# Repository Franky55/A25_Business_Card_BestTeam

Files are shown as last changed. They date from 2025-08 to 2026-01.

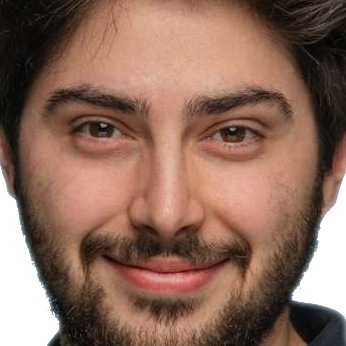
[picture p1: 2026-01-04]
code/web/photos/frank.png

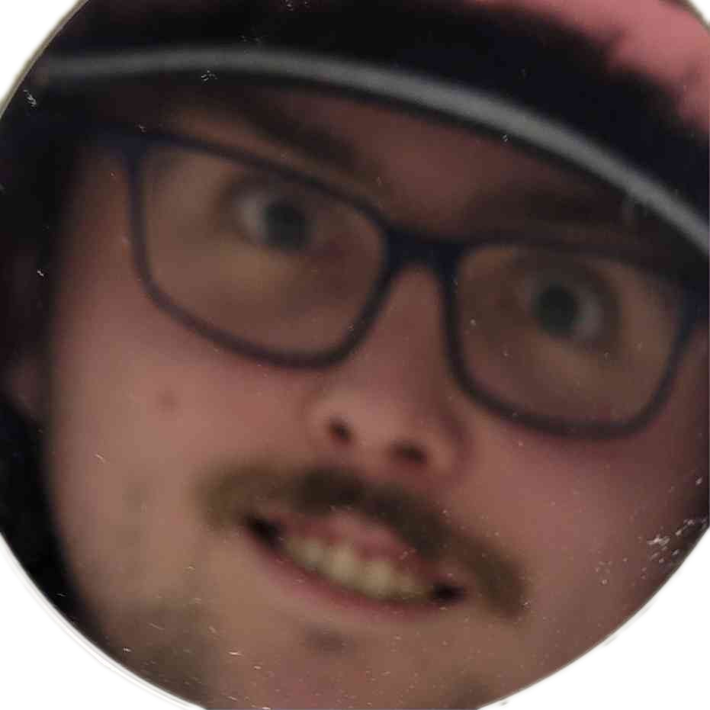
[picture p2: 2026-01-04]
code/web/photos/julien.png

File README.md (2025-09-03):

# C3I A25\_Business\_Card

Concours de Conception de Circuits Imprimés – Université de Sherbrooke, Automne 2025

## Thème : Carte professionnelle (Business Card)

Bienvenue à la compétition de conception de PCB de l’Université de Sherbrooke, édition automne 2025 !
Cette année, le défi est de transformer la carte professionnelle traditionnelle en un **objet électronique unique, créatif et fonctionnel**.
Votre mission : concevoir un PCB au format carte de visite qui intègre des fonctionnalités innovantes, esthétiques et utiles dans un contexte professionnel réel.

---

## Déroulement

Capture d’écran du 2025-09-03 15-49-03

* **25 août** : Lancement de la compétition et ouverture des inscriptions
* **3 octobre** : Date limite d’inscription
* **10 octobre** : Date limite de sélection d’idée (formulaire fourni sur GitHub et Discord)
* **25 août au 31 décembre 23h59** : Période de conception et développement
* **Dates de commande des PCB et pièces** :

  * 19 septembre\* (LCSC)
  * 3 octobre\* (LCSC)
  * 17 octobre\* (LCSC)
  * 31 octobre\* (LCSC)
  * 14 novembre
  * 28 novembre
  * 12 décembre\*\* (commande finale, réception non garantie avant la fin)
* **Décembre** : Finalisation des projets
* **31 décembre 23h59** : Remise finale (schémas, Gerber, BOM, photos, doc)
* **5 janvier 2026** : Journée de l’événement et présentations publiques

---

### Répertoire "Template"  
Le répertoire "Template" contient tous les documents à remplir pour participer à la compétition. Vous y trouverez :  
- Formulaire d'idée (à remplir)
- Formulaire d'inscription (à remplir)
- Condition et termes de l'inscription
- TEMPLATE de PowerPoint
- TEMPLATE pour la documentation

---

### Répertoires code, elec et mech  
Chacun de ces répertoires contient de la documentation de départ pour vous guider. Consultez la section "doc". Ces répertoires sont également là pour vous aider à vous organiser lors du développement de votre règle.

---

### Comment forker le dépôt

1. Accédez au dépôt GitHub officiel à l'adresse suivante : `https://github.com/CCI-udes/H25_Pomodoro`.
2. Cliquez sur le bouton "Fork" en haut à droite de la page du dépôt.
3. Sélectionnez votre propre compte GitHub comme destination du fork.
4. Clonez le dépôt forké sur votre machine locale en utilisant la commande suivante :
   ```bash
   git clone https://github.com/<votre-utilisateur>/E25_Wearable.git
   ```

---

## Règlement

* Équipes de **1 à 3 personnes**
* Frais de participation : **10 \$ / membre** OU **courriel de commandite** (gabarits fournis)
* Dimensions maximales PCB : **88,9 mm x 50,8 mm**
* BOM maximum : **50 \$**
* Coût de développement total : **125 \$**
* Utilisation de **DevBoard permise** (pénalité de points si dans la version finale)
* Tous les types de composants acceptés (Bluetooth, NFC, OLED, etc.)
* Batterie rechargeable permise si formation suivie et protocole respecté
* Objectif : **s’amuser et apprendre** !

---

## Remise

Chaque équipe doit fournir via son fork GitHub :

* Schéma électrique (PDF)
* Fichiers Gerber du PCB + projet EDA OU PDF coloré des couches
* Photo(s) du PCB assemblé (avec et sans boîtier)
* BOM conforme aux normes C3I
* Documentation complète du projet

---

## Évaluation

Les projets seront notés sur un total de **250 points**, selon :

* **Idée \[15 pts]** (juges + vote des participants)
* **Fonctionnalité \[35 pts]** (implémentation et compréhension)
* **Complexité \[45 pts]** (hardware + software)
* **Gestion des ressources \[25 pts]** (BOM + commandes)
* **Démonstration \[55 pts]** (oral, écrit, esthétique)
* **Conception électronique \[75 pts]** (choix composants, schéma, PCB, assemblage, soudures)

---

## Prix

* 🏆 **Prix de conception** – Total 250 pts
* ⚡ **Prix du gningnégnieur** – Total 170 pts (créativité et apprentissage valorisés)
* 💼 **Prix du vendeur** – Total 125 pts (gestion, organisation, finition)

---

## Ressources utiles

* **Microcontrôleurs recommandés** : ESP32-C3, ESP32-S3, RP2040, RP2350, ch32v003
* **Logiciels de conception** : KiCad, Altium, EasyEDA (+ tutoriels fournis dans le doc)
* **Idées de business cards électroniques** : [Hackaday](https://hackaday.com/tag/pcb-business-card/), [Reddit](https://www.reddit.com/r/PCB/comments/14jk8cz/pcb_business_card_ideas/), [Exemples NFC](https://www.instructables.com/PCB-Business-Card-With-NFC/)
* **Discord** : [Lien d’invitation](https://discord.gg/xeSqf3N3Hw)

---

## Contacts

* Jacob Turcotte – Président – `Jacob.Turcotte@usherbrooke.ca`
* Miriam Caisse – Vice-présidente – `Miriam.Caisse@usherbrooke.ca`
* Jordan Gagnon – Trésorier – `Jordan.Gagnon@usherbrooke.ca`
* Céleste-Lyi Martel – Marketing – `Celeste-lyi.martel@usherbrooke.ca`

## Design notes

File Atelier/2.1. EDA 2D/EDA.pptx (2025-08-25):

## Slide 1

Les logiciels d'EDA,
Electronic Design Automation
par où commencer ?

Présentation par : Miriam Caisse
Groupe technique CCI

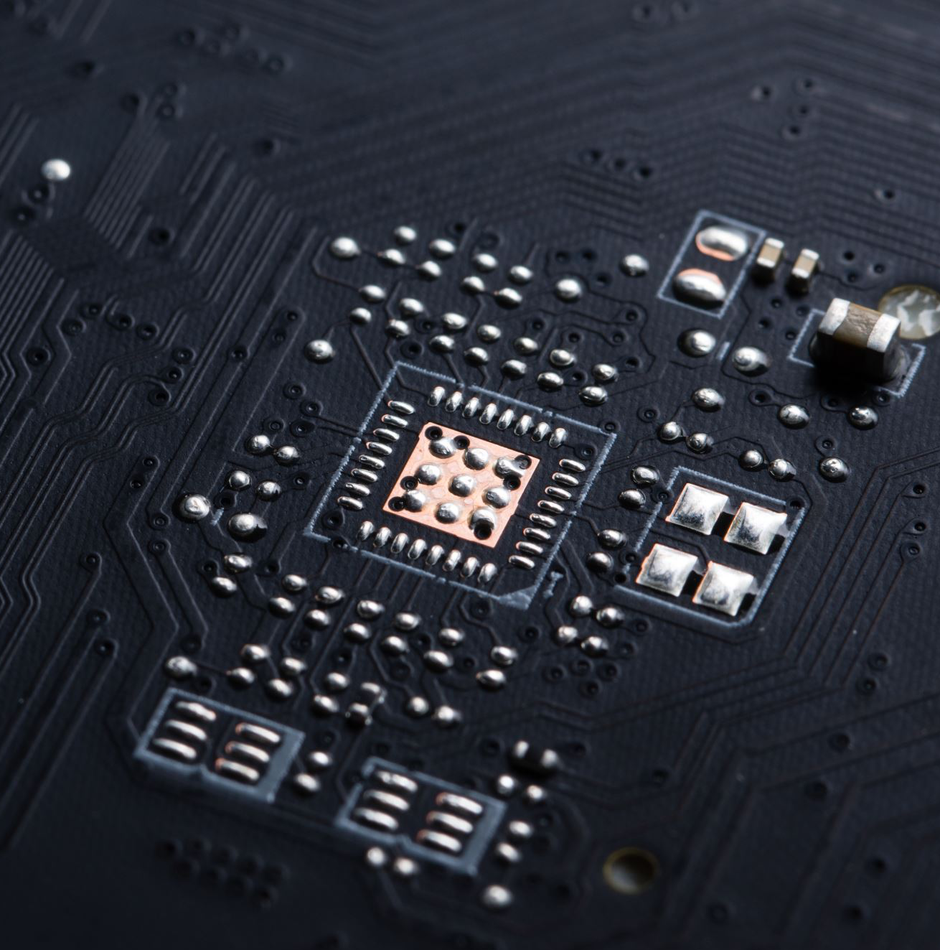
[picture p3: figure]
Gros plan de la carte de circuit imprimé

## Déroulement de la présentation

CCI – Miriam Caisse

À quoi ça sert ?

1

Comment choisir ?

2

Période de questions

3

## À quoi ça sert

Simuler des circuits électriques*
Faire des schémas électriques
Faire des PCBs (Circuits imprimés)

*Pas tous les logiciels

Le logiciel que vous allez choisir sera votre outil principal au courant du projet. Apprenez à le connaître!

## Déroulement de la présentation

À quoi ça sert ?

1

Comment choisir ?

2

Période de questions

3

## Comment choisir son logiciel ?

KiCad
Et plus encore
EasyEDA
Altium

## Comment choisir son logiciel ?

Sample Footer Text

Logiciel | Avantages | Inconvénients
KiCad | Gratuit Librairies robustes Facile à utiliser Open source -> des plugins ! | Certaines fonctionalitées nécessitent plus d'apprentissage
EasyEDA | Gratuit Très léger Facile à utiliser Composants LCSC à portée de main | Manque de fonctionnalités avancées
Altium | Capable de faire des simulations complexes -> excellent pour des circuits appliqués aux signaux A des fonctionnalités de design PCB avancé | Besoin d'une license Logiciel lourd Prend plus de temps à apprendre

## Déroulement de la présentation

À quoi ça sert ?

1

Comment choisir ?

2

Période de questions

3

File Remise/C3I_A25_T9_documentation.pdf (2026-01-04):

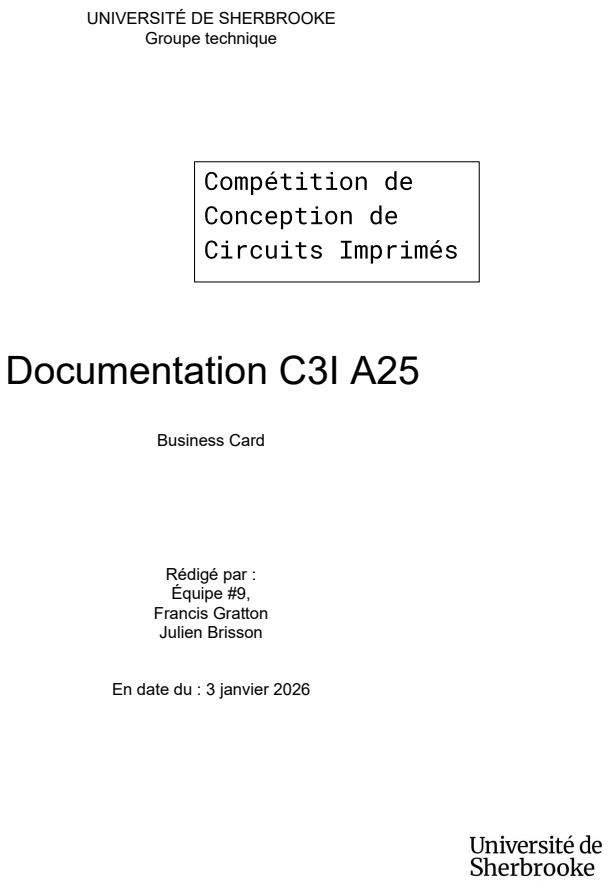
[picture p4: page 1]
Groupe technique; Documentation C3I A25; Business Card; Rédigé par : Équipe #9, Francis Gratton Julien Brisson

UNIVERSITÉ DE SHERBROOKE

En date du : 3 janvier 2026

## Table des matières

1. Introduction | 3
1.1. Contexte d’application | 3
1.2. Contraintes du projet | 3
1.2.1. Contraintes technologiques | 3
1.2.2. Contraintes de temps et de budget | 3
1.3. Description du produit réalisé | 3
1.3.1. Présentation globale | 4
2. Développement | 5
2.1. Conception électronique | 5
2.1.1. Choix technologiques | 5
2.1.2. Schémas électriques et conception PCB | 5
2.2. Conception informatique | 7
2.2.1. Présentation globale du code | 7
2.2.2. Librairies | 7
2.3. Gestion | 8
2.3.1. Temps | 8
2.3.2. Budget | 8
3. Conclusion | 10

## 1. Introduction

1.1. Contexte d’application

Business Card est la meilleure carte d’affaires à remettre à un futur employeur. Lorsqu’il s’agit de donner une carte d’affaires à quelqu’un, celle-ci se démarque complètement des autres. Le client peut l’utiliser pour se souvenir de nous et pour comprendre ce que nous sommes capables d’accomplir.

Ce projet a pour objectif de permettre de remettre une carte d’affaires à un futur employeur afin de se démarquer de la concurrence.

La carte est destinée à être utilisée lors de grands événements, tels que des salons ou des foires d’emploi, afin d’échanger avec de potentiels employeurs. Elle permet de laisser une impression plus marquante qu’un simple CV, semblable à celui de la majorité des candidats.

Notre carte comporte une bille numérique, pour s’assurer de toujours savoir où est le sol, et de belles lumières pour attirer l’attention lorsqu’elle est agitée.
1.2. Contraintes du projet
1.2.1. Contraintes technologiques

C3I exige de faire un PCB qui respecte le thème et le budget en respectant les normes de PCB. Pour le projet, la limitation que nous nous somme mis est de ne pas utiliser de MCU et seulement utiliser une coin cell battery.

1.2.2. Contraintes de temps et de budget

La contrainte de temps et le fait qu’on ne pouvait pas ramasser les composantes à Sherbrooke, à limiter beaucoup le budget de développement et réduit le temps investi sur le nombre de prototype. Donc, notre prototype est le projet final.
1.3. Description du produit réalisé

Pour le contrôle du projet, nous n'avons pas utilisé de micro contrôleur. Pour ce faire, nous avons 2 circuits qui contrôlent les alimentations. Nous utilisons des systèmes numériques et analogiques.

L’alimentation est faite par une coin cell battery. Elle est rechargeable par panneau solaire.

Toutes les fonctionnalités dont le RGB et le inclinomètre qui se déplace comme une bille à réussi à être implémenté. Nous avons aussi fait une page web qui est hébergée sur un serveur maison. Qui est accessible par le code QR sur la carte.

1.3.1. Présentation globale

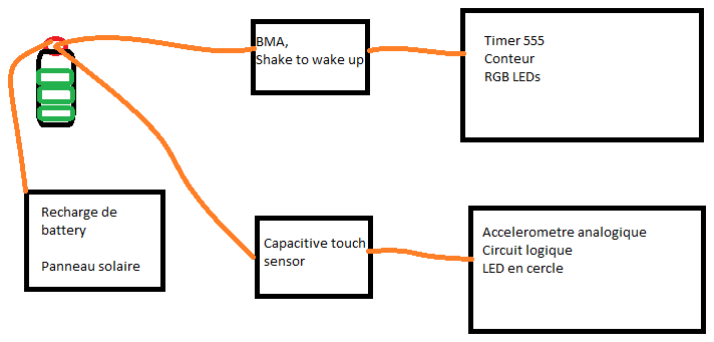
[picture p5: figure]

Le PCB est constitué de 3 circuits principaux :

La recharge :
Ce circuit est composé de panneaux solaires qui permettent de recharger la batterie.

Les LED RGB :
Ce circuit utilise un accéléromètre pour détecter lorsque la carte est secouée. Lorsqu’un mouvement est détecté, le circuit active les LED RGB pour créer un effet lumineux spectaculaire.

Le capacitive touch :
Ce circuit est un bouton capacitif qui permet d’activer le mécanisme de la bille se déplaçant vers le sol.

## 2. Développement

2.1. Conception électronique
2.1.1. Choix technologiques

Notre défi principal pour ce projet était de ne pas utiliser de microcontrôleur. Nous avons donc utilisé de nombreux circuits intégrés logiques, tels que des ampli-op, des portes logiques et des inverseurs, pour nos circuits.

Nous avons décidé d’implémenter un module de contrôle d’alimentation par carte (soit deux au total). Nous utilisons donc un BMA400 pour détecter les mouvements de la carte et alimenter les LED RGB, ainsi qu’un IQS228B pour créer un bouton capacitif directement sur la carte (un bouton composé uniquement de traces).

2.1.2. Schémas électriques et conception PCB

Le PCB est divisé en cinq sous-systèmes. En premier lieu, nous avons l’alimentation et la recharge de la batterie. Par la suite, l’alimentation est distribuée vers deux autres systèmes. Le premier concerne les LEDs RGB et leur « trigger », le BMA400. Le second regroupe les LEDs du cercle ainsi que leur « trigger », le IQS228B.

Les LEDs RGB sont présentées aux pages 2 et 3. À la page 2, on peut voir le BMA400, qui est utilisé comme « trigger » d’horloge pour la bascule (U2) lors d’une agitation. La bascule contrôle l’alimentation du reste du circuit RGB à l’aide d’un MOSFET de type P. Chaque « trigger » provoque une alternance de l’état de la sortie de la bascule.

Lorsque l’alimentation est activée, le timer 555 commence à fonctionner afin de générer l’horloge du compteur. Le compteur se réinitialise une fois qu’il atteint la valeur 4. Les sorties du compteur sont ensuite envoyées vers un sélecteur, ce qui permet de choisir le circuit de LEDs à alimenter. (L’inverseur U15 n’est pas utilisé en raison d’une erreur d’interprétation de la datasheet.)

Chaque couleur de LED utilise le même circuit. La LED est activée par un MOSFET de type N. Ce MOSFET est contrôlé par la charge et la décharge d’un condensateur connecté à sa gate. Le temps de charge est déterminé par le circuit mentionné précédemment ainsi que par la résistance de 250 kΩ. La décharge, quant à elle, est déterminée par la résistance de 250 kΩ et celle de 1,8 MΩ.

Le sous-système du IQS228B est simple, nous avons répliqué le schéma sur la «datasheet» et ajouté la sortie pour alimenter directement le module du cercle de LEDs.

La logique du cercle de LEDs provient de l’accéléromètre analogique. La sortie de l’accéléromètre est acheminée dans une chaîne de diviseurs de tension et d’amplificateurs opérationnels. La sortie de ces circuits nous fournit une notation thermométrique indiquant qu'elle LED doit être allumée. Les valeurs des résistances ont été déterminées à l’aide de simulations et d’essais-erreurs afin d’identifier les combinaisons avec la meilleure réactivité

Cette notation est ensuite transformée en notation one-hot à l’aide d’une série de portes NOT et AND, ce qui permet d’allumer une seule LED à la fois. Ce processus est appliqué uniquement pour l’axe X, avec 8 positions possibles. L’axe Y, quant à lui, est utilisé pour déterminer si l’on se trouve à droite ou à gauche du cercle, via un système similaire à celui décrit ci-dessus.

Ainsi, nous obtenons nos 16 LEDs. Il est important de noter que, puisque le cercle est divisé en deux moitiés égales, notre axe de symétrie doit se situer entre deux LEDs. C’est pour cette raison que l’accéléromètre ADXL est incliné pour correspondre à l’orientation des LEDs du cercle.

2.2. Conception informatique
2.2.1. Présentation globale du code

Puisque la majorité de notre PCB est analogique, nous avions très peu de programmation à effectuer. Le seul composant nécessitant une programmation dans notre projet est le BMA400, qui doit être configuré pour obtenir les interruptions requises des composants.

Nous avons également créé un site web démonstratif accessible via le code QR situé sur la carte. Celui-ci nous permet d’ajouter davantage d’informations sans augmenter de manière significative la complexité du projet.

2.2.2. Librairies

Nous avons utilisé deux librairies, soit une pour configurer le BMA400 avec les adresses mémoires adéquates et une pour se connecter en I2C au capteur afin de le programmer. Les deux librairies sont «SparkFun BMA400 Arduino Library» et «Wire» respectivement. Le code est celui trouvé sur le github de la librairie.
Le site web a été créé sans librairie, mais en utilisant un outil appelé «GitFolio» et du javascript / html / css de base.

2.3. Gestion
2.3.1. Temps

Nos échéances concernaient les dates de commande des PCB et des composantes. Nous avons constaté que nous disposions de peu de temps au début du mois de novembre, ce qui nous a empêchés de réaliser un premier prototype. Nous avons donc dû produire une seule itération de notre carte au début de décembre. Nous n’avons eu le temps d’effectuer qu’une seule révision du schéma et avons apporté quelques correctifs à certains composants lors de la deuxième commande.

Nous avons manqué une remise importante, soit celle de ce document, ce qui explique son retard. Nous utilisons Discord comme agenda avec des notifications, mais nous avons malheureusement manqué la plus importante.

Concernant le PCB, un assemblage de tests a été réalisé au début de décembre afin de valider certains systèmes. Le 21 décembre, nous avons procédé à l’assemblage du PCB principal, puis le 22 décembre, nous y avons apporté quelques correctifs.

Le plan initial consistait à coller les deux PCB ensemble. Toutefois, puisque la compétition exige que les juges puissent vérifier les PCB, nous avons dû consacrer une journée supplémentaire, le 3 janvier, à la conception d’un support «bracket» permettant de maintenir les deux PCB ensemble.

2.3.2. Budget

Notre budget de développement était de 125$. Puisque nous avons décidé de réaliser un projet à 99% analogique, certains composants commandés initialement ne répondaient pas aux spécifications requises. Nous avons donc dû acheter des composants de meilleure qualité, offrant de meilleures tolérances ou caractéristiques techniques. Selon nos estimations avant l’envoi des commandes, le coût total du développement s’élève à environ 122$. Voici pourquoi:

BOM #1 | 97.76$
BOM #2 | 8.22$
PCB | 9$
Stencil | 7$
Total | 121.98$

Suite au prototypage, le coût d’un seul PCB assemblé est estimé à 48,84 $ pour les composants, 9 $ pour la fabrication de cinq PCB (soit 1,80 $ par PCB) et 7 $ pour un stencil réutilisable. Ce qui nous donne un total de 50.64 $ par PCB. Ce qui nous met sous le coût demander par compétition.

## 3. Conclusion

L’idée initiale est bien représentée sur notre PCB.

Si nous devions recommencer, nous utiliserions un microcontrôleur (MCU) afin de simplifier les schémas. Cela nous permettrait aussi de réduire les coûts et de pousser nos idées encore plus loin en ajoutant davantage de fonctionnalités.

## Annexe A

## Page 1

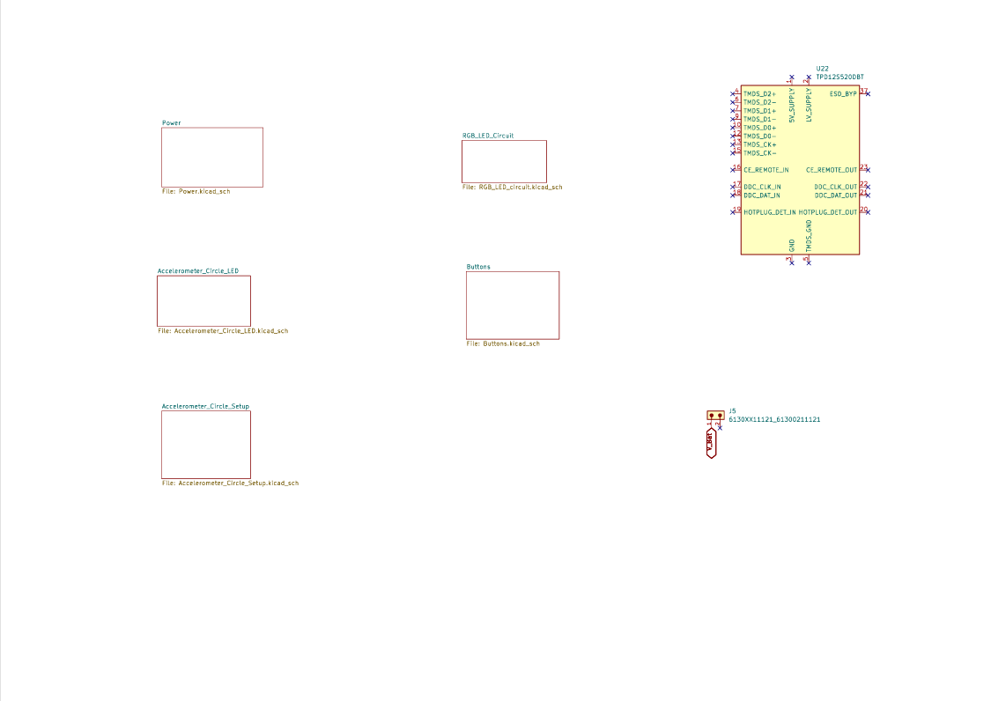
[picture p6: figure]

## Page 2 (POWER CONTROLS)

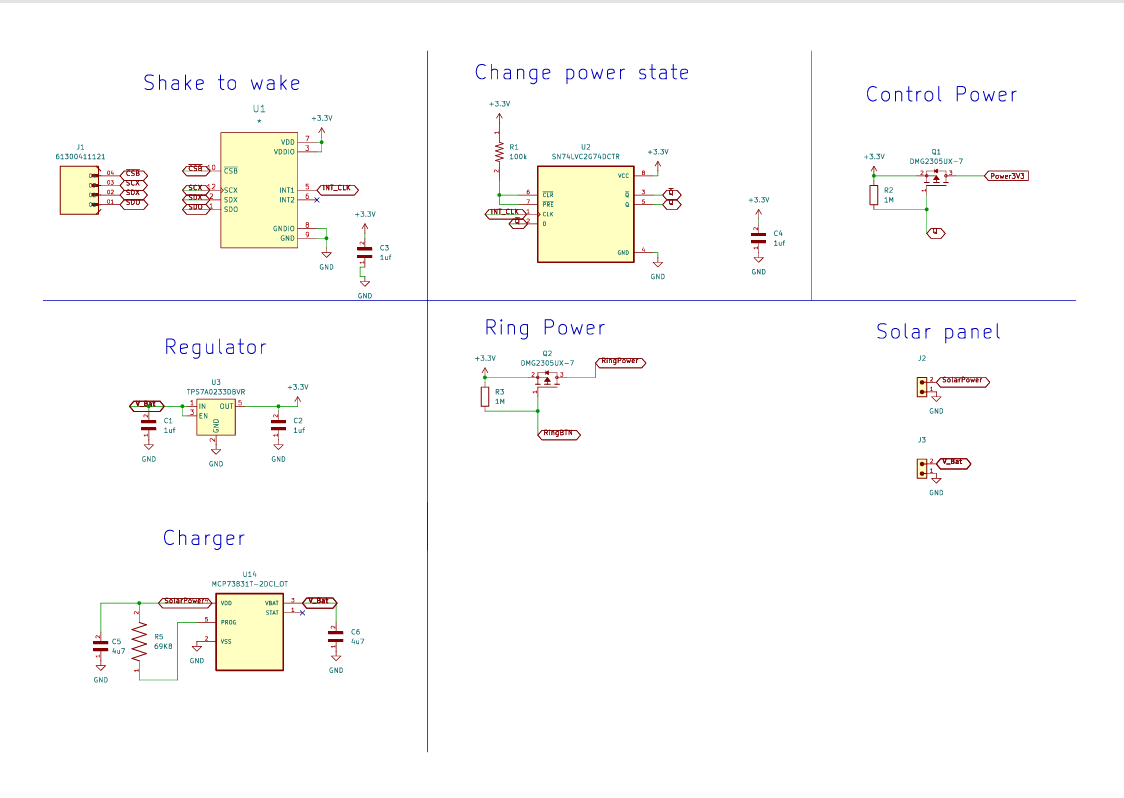
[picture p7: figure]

## Page 3 (RGB LED LOGIC)

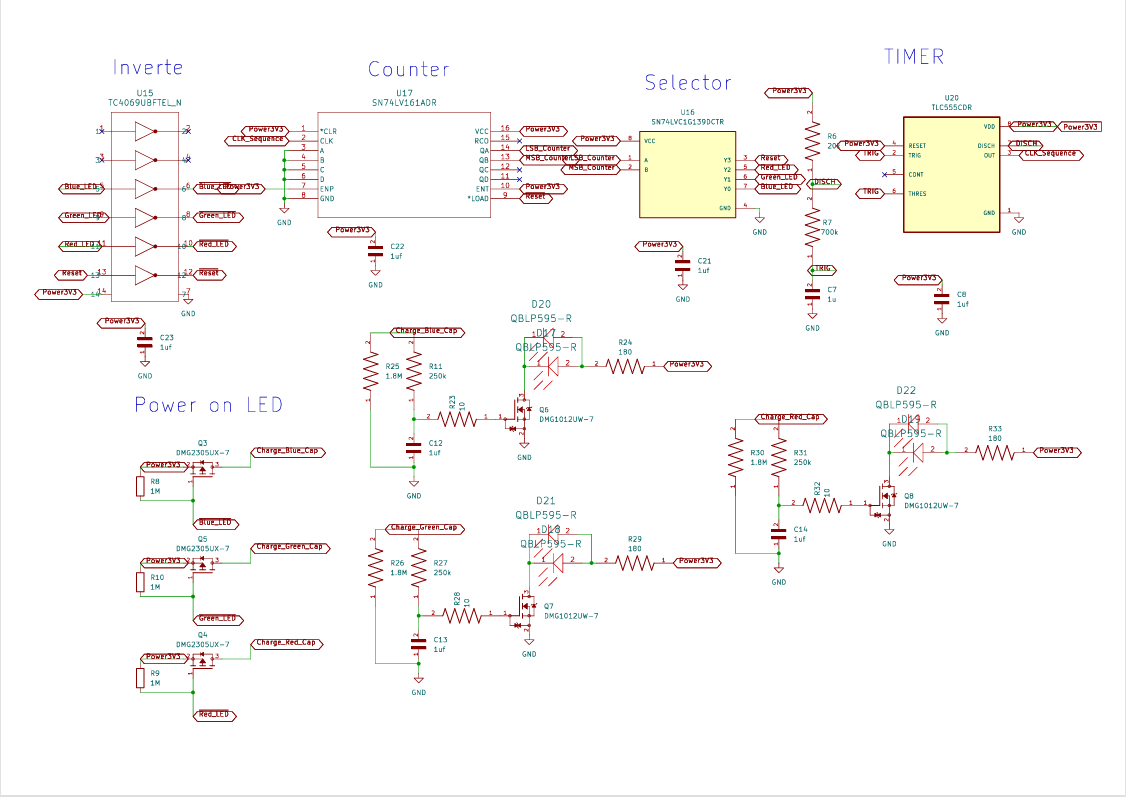
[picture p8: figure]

## Page 4 (LED CIRCLE ARRAY)

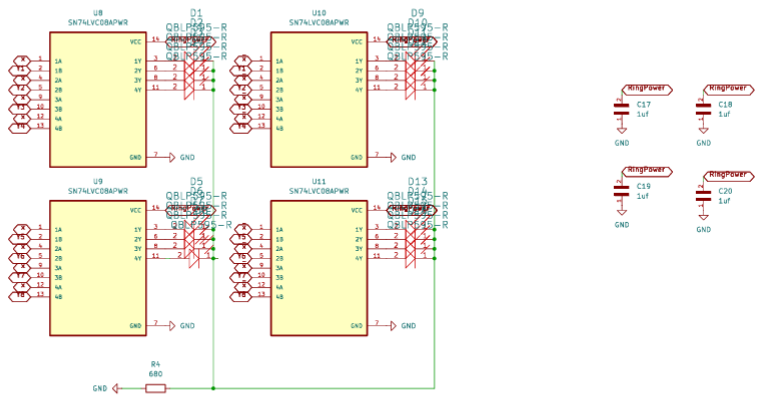
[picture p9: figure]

## Page 5 (TOUCH SENSOR IC)

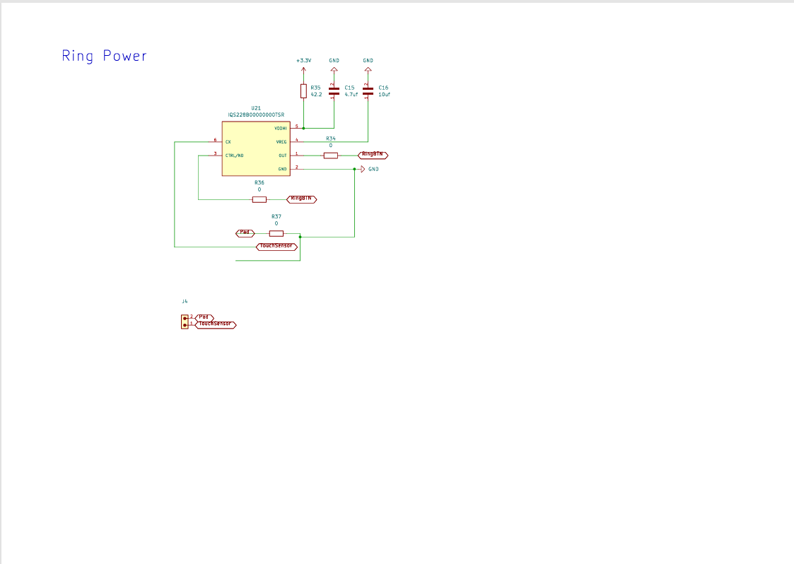
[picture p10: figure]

## Page 6 (LED CIRCLE LOGIC)

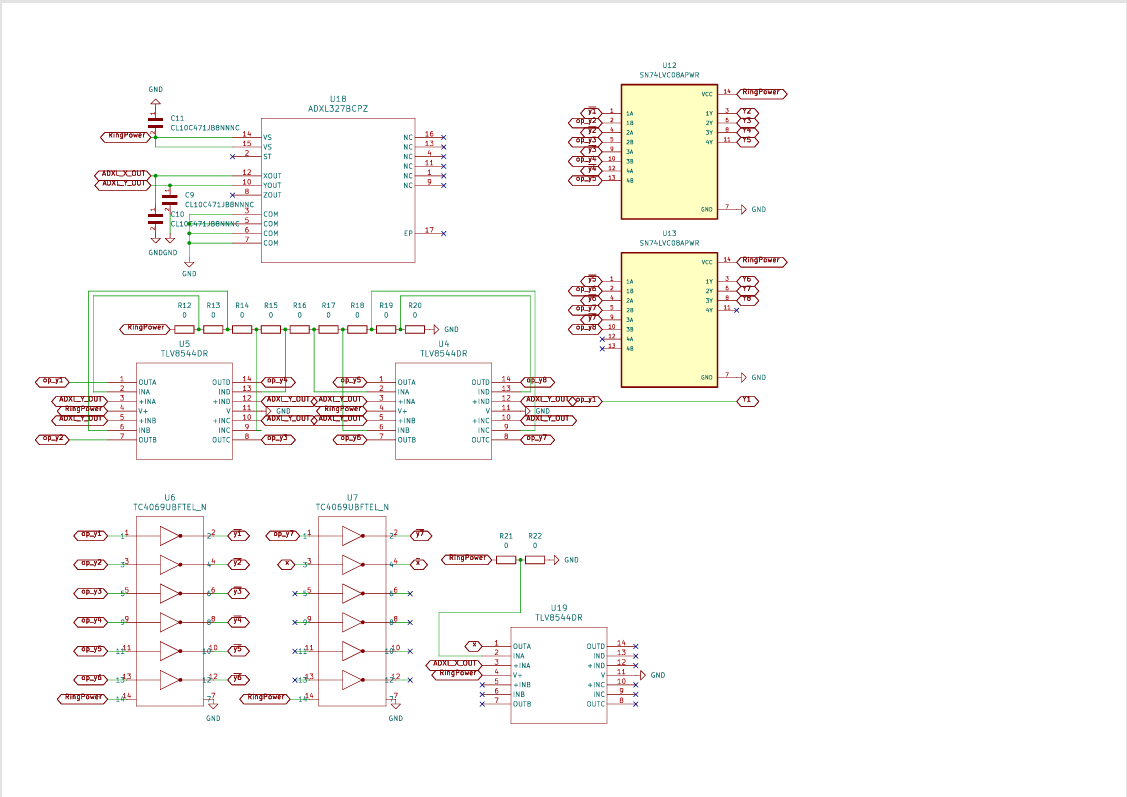
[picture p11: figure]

## Top Layer

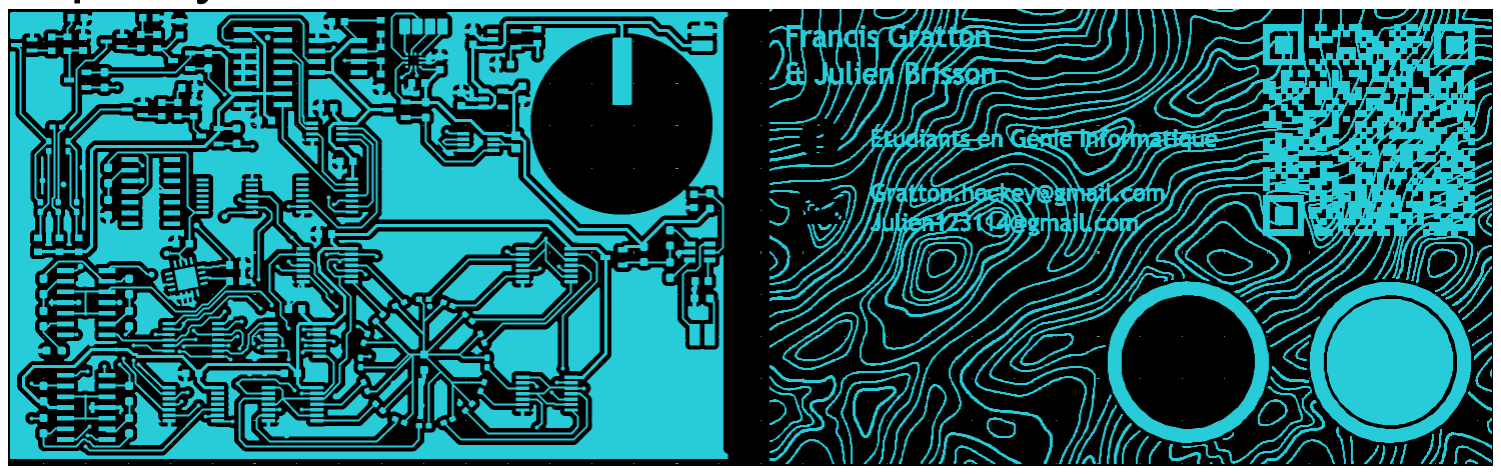
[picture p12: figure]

## Bottom Layer

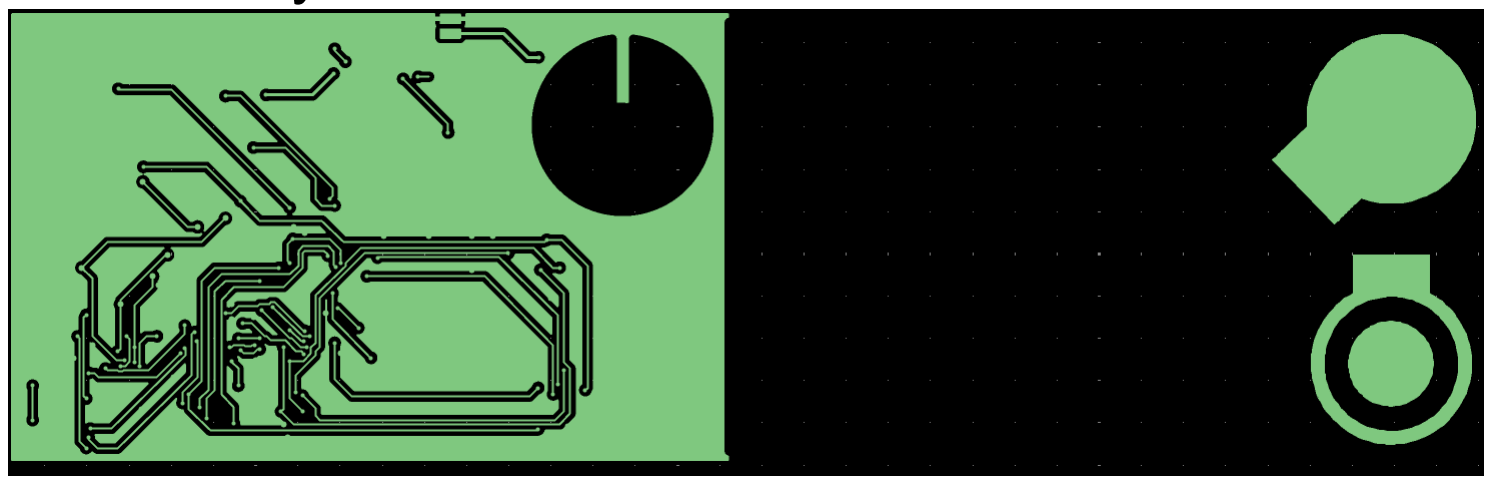
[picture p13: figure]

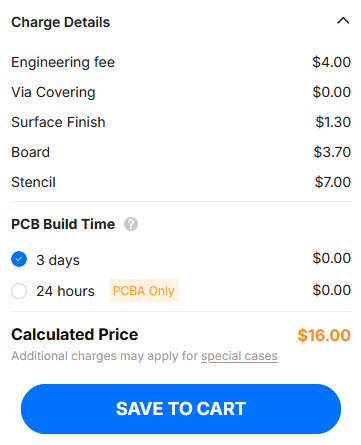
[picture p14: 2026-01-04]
Remise/prix.png

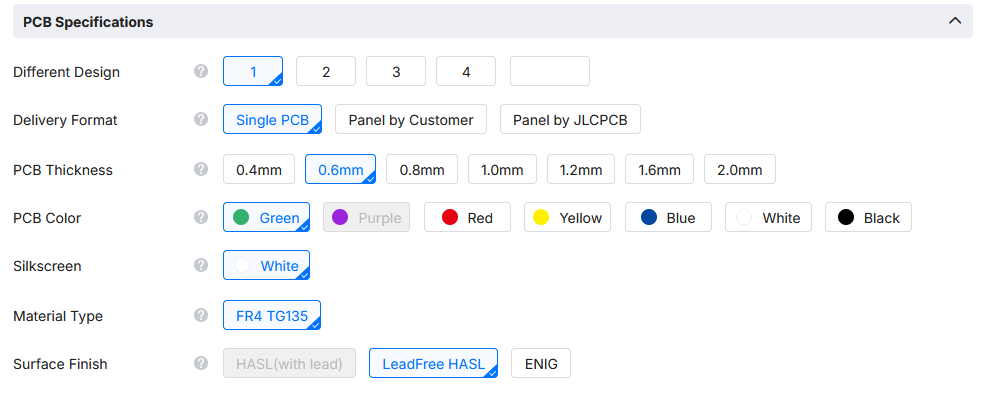
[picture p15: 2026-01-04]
Remise/pcb.png

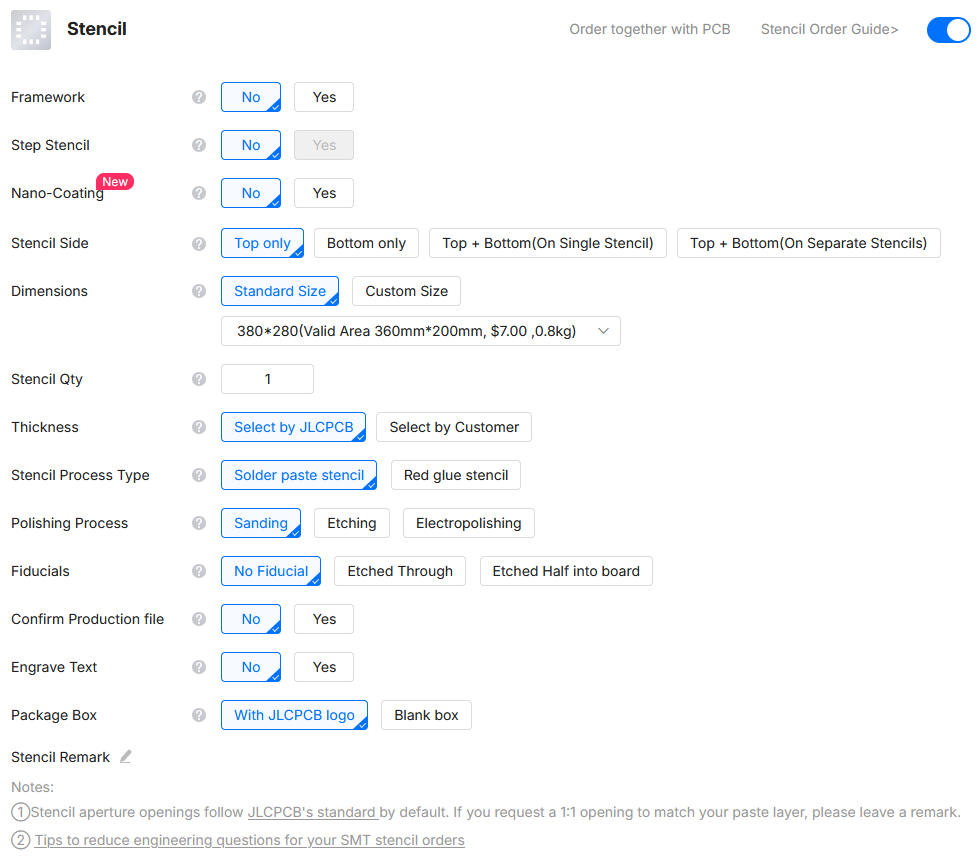
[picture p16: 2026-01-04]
Remise/stencil.png

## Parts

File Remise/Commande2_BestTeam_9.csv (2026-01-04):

Index | Quantity | Part Number | Manufacturer Part Number | Description | Customer Reference | Available | Backorder | Unit Price | Extended Price CAD
1 | 10 | 311-20.0KHRCT-ND | RC0603FR-0720KL | RES 20K OHM 1% 1/10W 0603 |  | 10 | 0 | 0.01600 | 0.16
2 | 10 | P698KHCT-ND | ERJ-3EKF6983V | RES SMD 698K OHM 1% 1/10W 0603 |  | 10 | 0 | 0.05400 | 0.54
3 | 10 | 541-5283-1-ND | CRCW0603249KFKEAC | RES 249K OHM 1% 1/10W 0603 |  | 10 | 0 | 0.04600 | 0.46
4 | 10 | 541-1.80MHCT-ND | CRCW06031M80FKEA | RES SMD 1.8M OHM 1% 1/8W 0603 |  | 10 | 0 | 0.04800 | 0.48
5 | 10 | A129679CT-ND | CRGCQ0603F180R | RES 180 OHM 1% 1/10W 0603 |  | 10 | 0 | 0.04400 | 0.44
6 | 30 | RMCF0603FT100KCT-ND | RMCF0603FT100K | RES 100K OHM 1% 1/10W 0603 |  | 30 | 0 | 0.01280 | 0.38
7 | 10 | 1276-1946-1-ND | CL10B105KP8NNNC | CAP CER 1UF 10V X7R 0603 |  | 10 | 0 | 0.00700 | 0.07
8 | 2 | 296-1336-1-ND | TLC555CDR | IC OSC SGL TIMER 2.1MHZ 8-SOIC |  | 2 | 0 | 1.24000 | 2.48
9 | 3 | 1497-1219-1-ND | XZVG68W-2 | LED GREEN CLEAR CHIP SMD |  | 3 | 0 | 0.40000 | 1.20
10 | 3 | 350-4452-1-ND | 5988A90107F | LED BLUE 470NM 0402 SMD |  | 3 | 0 | 0.46000 | 1.38
11 | 2 | DMG1012UW-7DICT-ND | DMG1012UW-7 | MOSFET N-CH 20V 1A SOT323 |  | 2 | 0 | 0.42000 | 0.84
12 | 10 | RMCF0603FT49K9CT-ND | RMCF0603FT49K9 | RES 49.9K OHM 1% 1/10W 0603 |  | 10 | 0 | 0.03200 | 0.32

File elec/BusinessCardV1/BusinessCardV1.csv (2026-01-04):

Reference | Qty | Value | DNP | Exclude from BOM | Exclude from Board | Footprint | Datasheet | DigiKey_Part_Number | Digikey_Part number
C1,C2,C3,C4,C8,C12,C13,C14,C17,C18,C19,C20,C21,C22,C23 | 15 | 1uf |  |  |  | CL10B105KP8NNNC:CAPC1608X90N |  | 1276-1946-1-ND
C5,C6 | 2 | 4u7 |  |  |  | CL10A475KP8NNNC:CAPC1608X90N |  | 1276-1044-1-ND
C7 | 1 | 1u |  |  |  | CL10C471JB8NNNC:CAPC1608X90N |  | 1276-1168-1-ND
C9,C10,C11 | 3 | CL10C471JB8NNNC |  |  |  | CL10C471JB8NNNC:CAPC1608X90N |  | 1276-1168-1-ND
C15 | 1 | 4.7uf |  |  |  | CL10B105KP8NNNC:CAPC1608X90N |  | 1276-1946-1-ND
C16 | 1 | 10uf |  |  |  | CL10B105KP8NNNC:CAPC1608X90N |  | 1276-1946-1-ND
D1,D2,D3,D4,D5,D6,D7,D8,D9,D10,D11,D12,D13,D14,D15,D16,D17,D18,D19,D20,D21,D22 | 22 | QBLP595-R |  |  |  | LED_SMD:LED_0402_1005Metric_Pad0.77x0.64mm_HandSolder
J1 | 1 | 61300411121 |  |  |  | HEADER1x4:HEADER1x4_SMD |  | 732-5317-ND
J2,J3,J4 | 3 | 6130XX11121_61300211121 |  |  |  | Header1x2:Header1x2_SMD |  | 732-5315-ND
J5 | 1 | 6130XX11121_61300211121 |  |  |  | Header1x2:SMD_Header |  | 732-5315-ND
Q1,Q2,Q3,Q4,Q5 | 5 | DMG2305UX-7 |  |  |  | DMG2305UX-7:SOT91P240X110-3N_DMG2305UX-7 |  | DMG2305UX-7DICT-ND
Q6,Q7,Q8 | 3 | DMG1012UW-7 |  |  |  | DMG1012UW-7:SOT65P222X110-3N |  | DMG1012UW-7DICT-ND
R1 | 1 | 100k |  |  |  | RC0603FR-07100KL:RESC1607X60N |  | 311-100KHRCT-ND
R2,R3,R8,R9,R10 | 5 | 1M |  |  |  | Resistor_SMD:R_0603_1608Metric_Pad0.98x0.95mm_HandSolder | ~ | ERJ-3EKF1004V
R4 | 1 | 680 |  |  |  | Resistor_SMD:R_0603_1608Metric_Pad0.98x0.95mm_HandSolder | ~
R5 | 1 | 69K8 |  |  |  | RC0603FR-0769K8L:RESC1608X55N |  | 311-69.8KHRCT-ND
R6 | 1 | 20k |  |  |  | RC0603FR-0769K8L:RESC1608X55N |  | 311-69.8KHRCT-ND
R7 | 1 | 700k |  |  |  | RC0603FR-0769K8L:RESC1608X55N |  | 311-69.8KHRCT-ND
R11,R27,R31 | 3 | 250k |  |  |  | RC0603FR-0769K8L:RESC1608X55N |  | 311-69.8KHRCT-ND
R12,R13,R14,R15,R16,R17,R18,R19,R20,R21,R22,R34,R36,R37 | 14 | 0 |  |  |  | Resistor_SMD:R_0603_1608Metric_Pad0.98x0.95mm_HandSolder | ~
R23,R28,R32 | 3 | 10 |  |  |  | RC0603FR-0769K8L:RESC1608X55N |  | 311-69.8KHRCT-ND
R24,R29,R33 | 3 | 180 |  |  |  | RC0603FR-0769K8L:RESC1608X55N |  | 311-69.8KHRCT-ND
R25,R26,R30 | 3 | 1.8M |  |  |  | RC0603FR-0769K8L:RESC1608X55N |  | 311-69.8KHRCT-ND
R35 | 1 | 42.2 |  |  |  | Resistor_SMD:R_0603_1608Metric_Pad0.98x0.95mm_HandSolder | ~
U1 | 1 | * |  |  |  | BMA400:XDCR_BMA400 |  | BMA400
U2 | 1 | SN74LVC2G74DCTR |  |  |  | SN74LVC2G74DCTR:SOP65P400X130-8N |  | 296-13273-1-ND
U3 | 1 | TPS7A0233DBVR |  |  |  | Package_TO_SOT_SMD:SOT-23-5 |  | TPS7A0233DBVR
U4,U5,U19 | 3 | TLV8544DR |  |  |  | TLV8544DR:D14_TEX | https://www.ti.com/lit/gpn/tlv8544
U6,U7,U15 | 3 | TC4069UBFTEL_N |  |  |  | TC4069UBFTELN:TSSOP14_TOS | https://toshiba.semicon-storage.com/info/docget.jsp?did=18696&prodName=TC4069UBFT
U8,U9,U10,U11,U12,U13 | 6 | SN74LVC08APWR |  |  |  | SN74LVC08APWR:SOP65P640X120-14N
U14 | 1 | MCP73831T-2DCI_OT |  |  |  | MCP73831T-2DCI_OT:SOT95P270X145-5N |  | MCP73831T-2DCI/OTCT-ND
U16 | 1 | SN74LVC1G139DCTR |  |  |  | SN74LVC1G139DCTR:SOP65P400X130-8N |  | 296-18235-1-ND
U17 | 1 | SN74LV161ADR |  |  |  | SN74LV161ADR:SN74LV161ADR | https://www.ti.com/lit/gpn/sn74lv161a |  | SN74LV161ADR
U18 | 1 | ADXL327BCPZ |  |  |  | ADXL327BCPZ:CP_16_5A_ADI | https://www.analog.com/media/en/technical-documentation/data-sheets/ADXL327.pdf
U20 | 1 | TLC555CDR |  |  |  | TLC555CDR:SOIC127P599X175-8N |  | 296-1336-1-ND
U21 | 1 | IQS228B00000000TSR |  |  |  | IQS228B00000000TSR:SOT95P280X100-6N
U22 | 1 | TPD12S520DBT |  |  |  | PCBArt:design | http://www.ti.com/lit/ds/symlink/tpd12s520.pdf

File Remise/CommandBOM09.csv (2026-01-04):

best team | Reference | qty | DigiKey_Part_Number
TEAM09 | C1,C2,C3,C4 | 10 | 1276-1946-1-ND
TEAM09 | C5,C6 | 10 | 1276-1044-1-ND
TEAM09 | C7,C8 | 18 | 1276-1168-1-ND
TEAM09 | D1,D2,D3,D4,D5,D6,D7,D8,D9,D10,D11,D12,D13,D14,D15,D16 | 36 | 3147-B1811URO-20D000113U1930CT-ND
TEAM09 | na | 4 | 3147-B1811NB--05D000113U1930CT-ND
TEAM09 | na | 4 | 3147-B1811NG--05D001013U1930CT-ND
TEAM09 | Q1,Q2,Q3,Q4,Q5 | 10 | DMG2305UX-7DICT-ND
TEAM09 | R1 | 25 | 311-100KHRCT-ND
TEAM09 | R2,R3,R8,R9,R10,R? | 25 | ERJ-3EKF1004V
TEAM09 | R4 | 2 | P680HCT-ND
TEAM09 | R5,R6,R7,R11 | 10 | 311-69.8KHRCT-ND
TEAM09 | U1 | 2 | BMA400
TEAM09 | U2 | 2 | 296-13273-1-ND
TEAM09 | U3 | 2 | TPS7A0233DBVR
TEAM09 | U4,U5,U19 | 6 | TLV8544DR
TEAM09 | U6,U7,U15 | 6 | TC4069UBFTELNCT-ND
TEAM09 | U8,U9,U10,U11,U12,U13 | 12 | SN74LVC08APWR
TEAM09 | U14 | 2 | MCP73831T-2DCI/OTCT-ND
TEAM09 | U16 | 2 | 296-18235-1-ND
TEAM09 | U17 | 2 | SN74LV161ADR
TEAM09 | U18 | 2 | ADXL327BCPZ
TEAM09 | Q? | 10 | BSS316NH6327XTSA1
TEAM09 | J1 | 4 | KXOB25-02X8F-TB
TEAM09 | R? | 10 | RMCF0603FT10R0CT-ND
TEAM09 | R? | 10 | RMCF0603FT681RCT-ND
TEAM09 | R? | 10 | 311-120KGRCT-ND
TEAM09 | R? | 25 | RMCF0603FT332KCT-ND
TEAM09 | U? | 2 | IQS228B00000000TSR

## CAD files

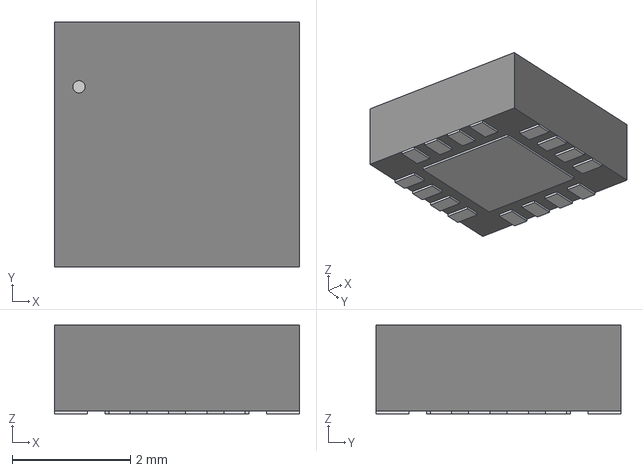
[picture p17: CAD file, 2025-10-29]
elec/BusinessCardV1/Components/ADXL327BCPZ/CP_16_5A_ADI.step
4.14 x 4.14 x 1.50 mm

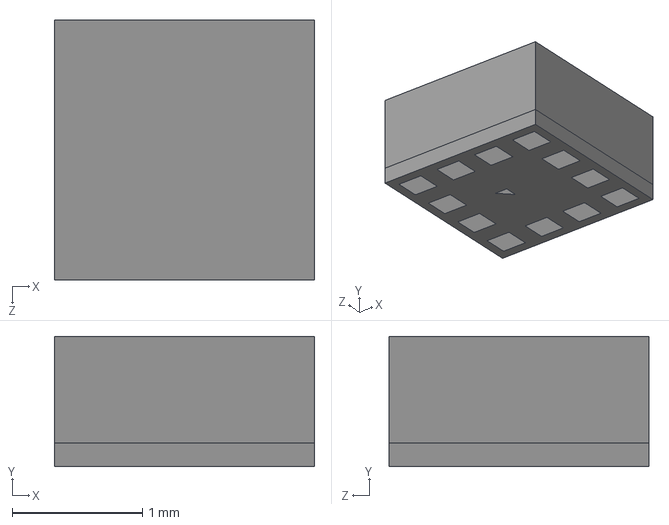
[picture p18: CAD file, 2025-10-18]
elec/BusinessCardV1/Components/BMA400/BMA400.step
2.00 x 1.00 x 2.00 mm

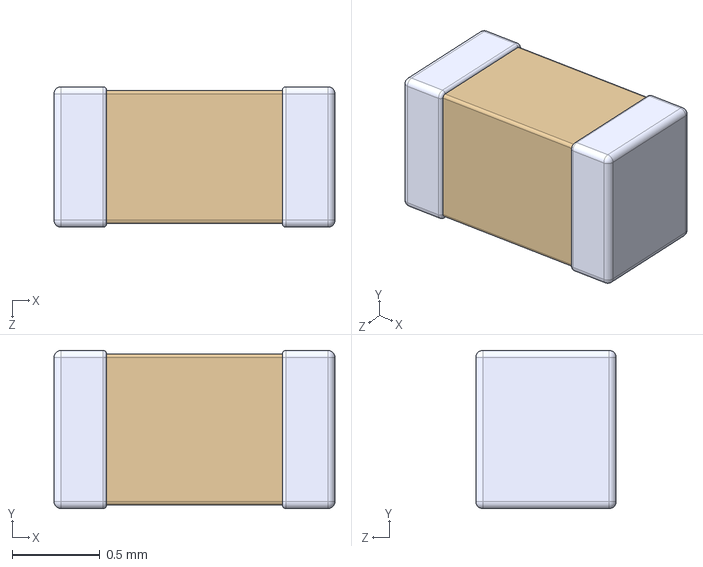
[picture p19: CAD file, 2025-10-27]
elec/BusinessCardV1/Components/CL10A475KP8NNNC/CL10A475KP8NNNC.step
1.60 x 0.9 x 0.8 mm

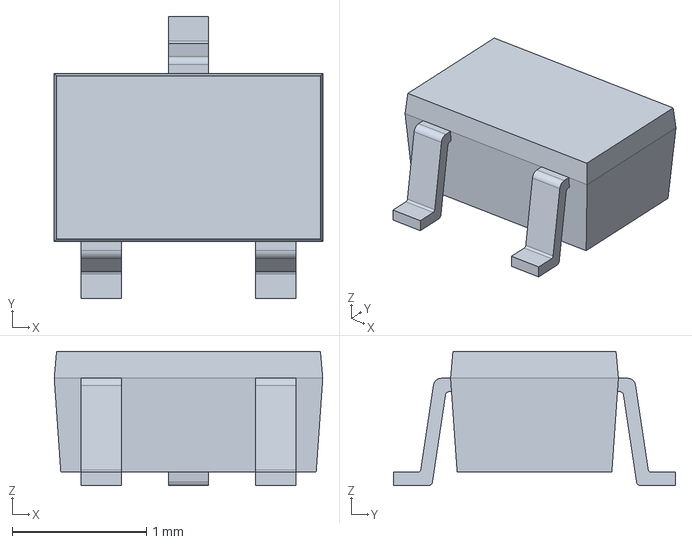
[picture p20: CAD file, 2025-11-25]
elec/BusinessCardV1/Components/DMG1012UW-7/DMG1012UW-7.step
2.00 x 2.10 x 1.00 mm

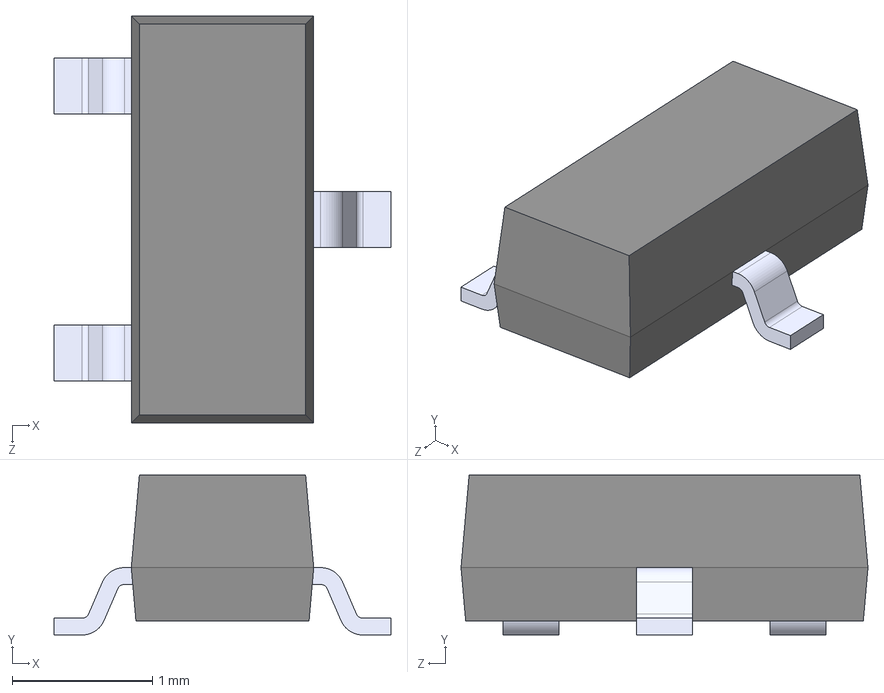
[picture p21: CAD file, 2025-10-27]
elec/BusinessCardV1/Components/DMG2305UX-7/DMG2305UX-7.step
2.40 x 1.14 x 2.90 mm

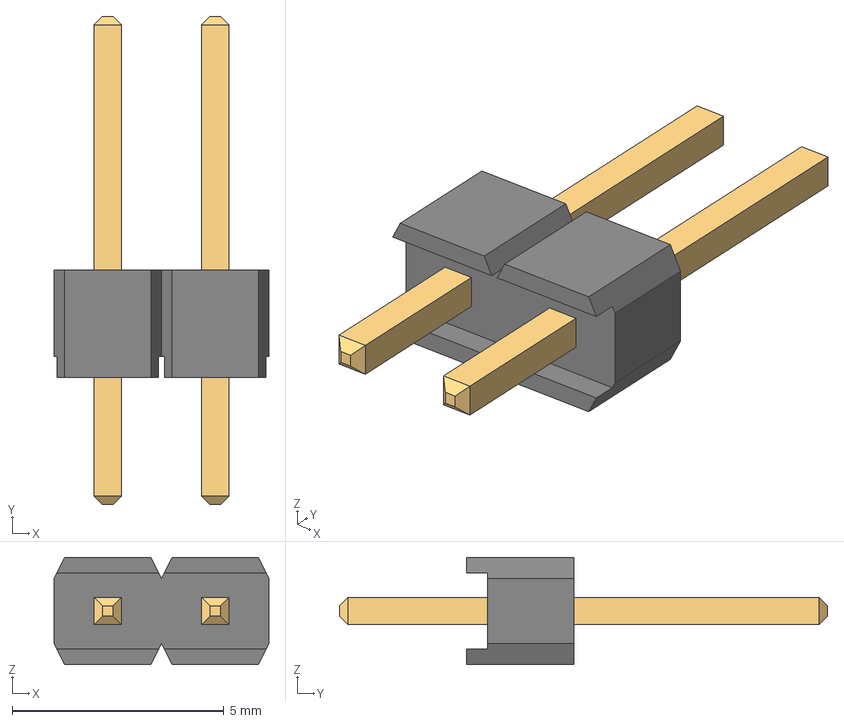
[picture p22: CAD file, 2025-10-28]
elec/BusinessCardV1/Components/Header1x2/Header1x2.step
5.08 x 11.5 x 2.54 mm
6130xx11121_PIN x 2

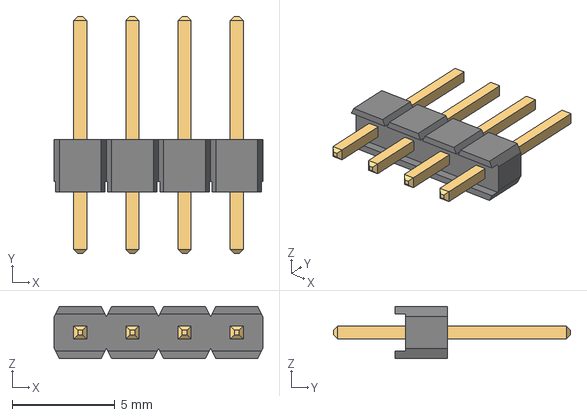
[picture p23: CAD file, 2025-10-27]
elec/BusinessCardV1/Components/Header1x4/Header1x4.step
10.2 x 11.5 x 2.54 mm
6130xx11121_PIN x 4

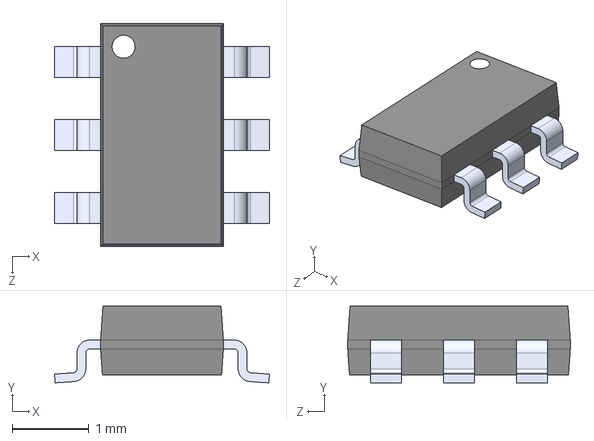
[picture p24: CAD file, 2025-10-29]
elec/BusinessCardV1/Components/IQS228B00000000TSR/IQS228B00000000TSR.step
2.80 x 1.00 x 2.90 mm

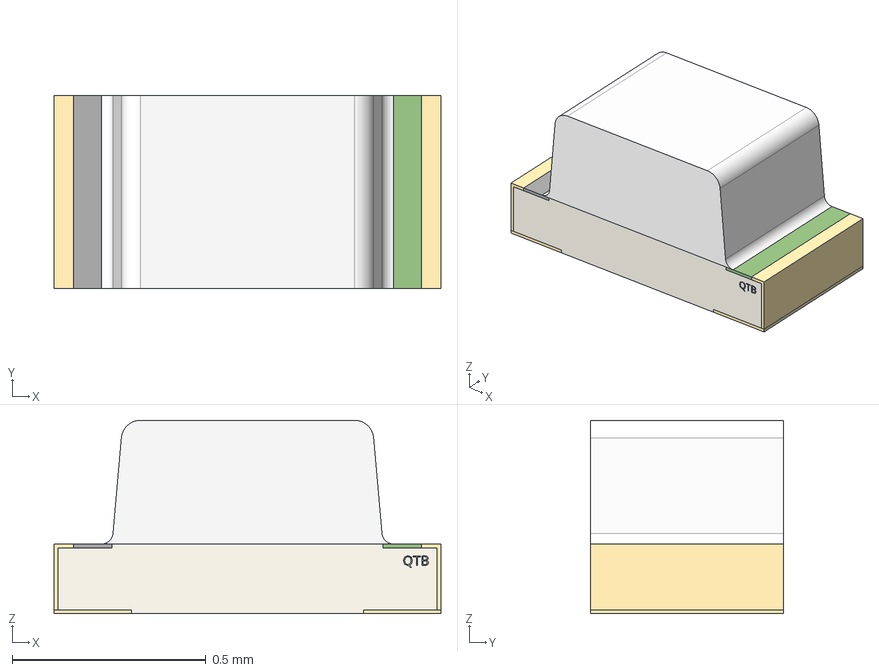
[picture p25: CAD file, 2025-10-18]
elec/BusinessCardV1/Components/QBLP595/QBLP595.step
1.00 x 0.5 x 0.5 mm
Side Pad 2
Resin
Polarity Mark 1
Substrate
Side Pad 1
Bottom Pad 2
Polarity Mark 2
Bottom Pad 1

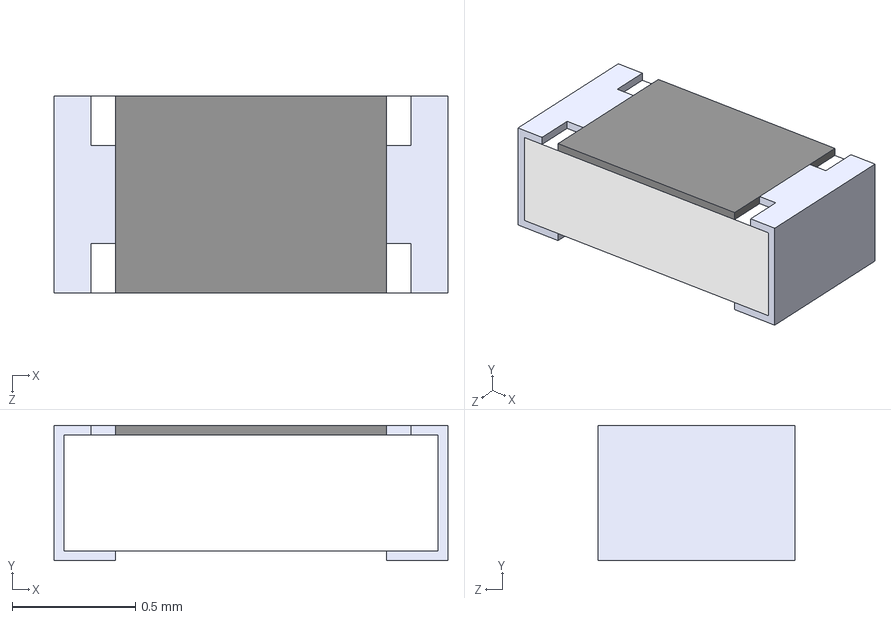
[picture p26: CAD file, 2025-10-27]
elec/BusinessCardV1/Components/RC0603FR-07100KL/RC0603FR-07100KL.step
1.60 x 0.55 x 0.8 mm

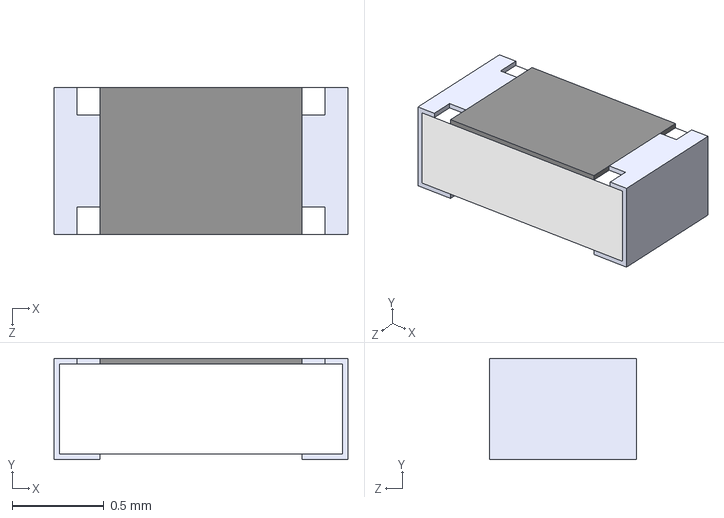
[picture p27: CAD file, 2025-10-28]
elec/BusinessCardV1/Components/RC0603FR-0769K8L/RC0603FR-0769K8L.step
1.60 x 0.55 x 0.8 mm

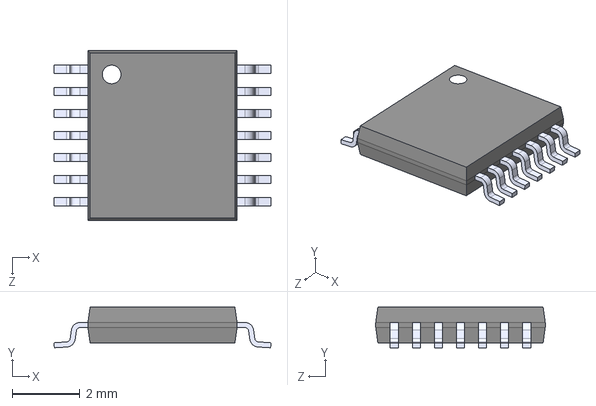
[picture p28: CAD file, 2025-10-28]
elec/BusinessCardV1/Components/SN74LVC08APWR/SN74LVC08APWR.step
6.40 x 1.20 x 5.00 mm

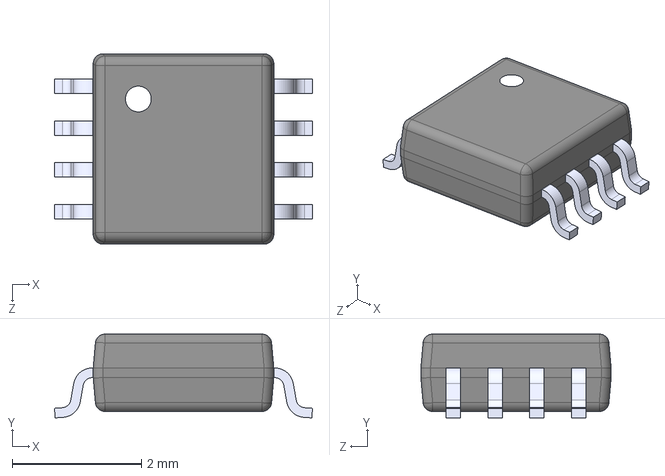
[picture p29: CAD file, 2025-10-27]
elec/BusinessCardV1/Components/SN74LVC1G139DCTR/SN74LVC1G139DCTR.step
4.00 x 1.30 x 2.95 mm

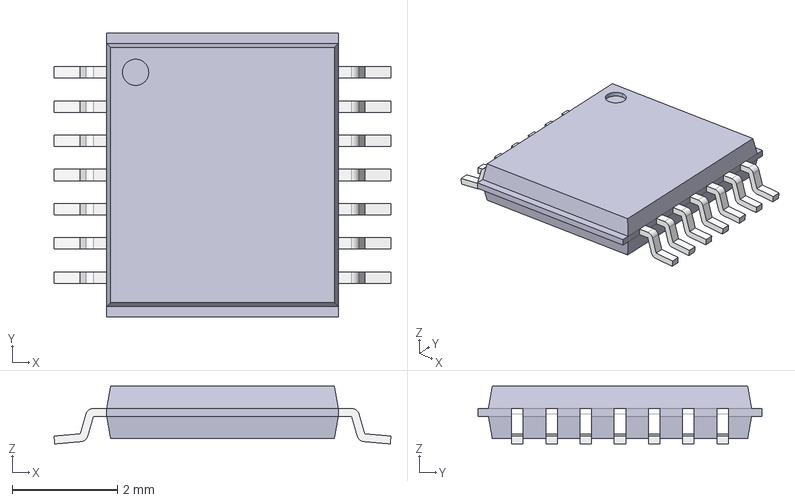
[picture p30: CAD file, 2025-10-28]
elec/BusinessCardV1/Components/TC4069UBFTELN/TSSOP14_z90.stp
6.40 x 5.40 x 1.10 mm

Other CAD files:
elec/BusinessCardV1/Components/TLC555CDR/TLC555CDR/TLC555CDR.step
elec/BusinessCardV1/Components/TLV8544DR/D0014A.stp
elec/BusinessCardV1/Components/MCP73831T-2DCI_OT/MCP73831T-2DCI_OT.step

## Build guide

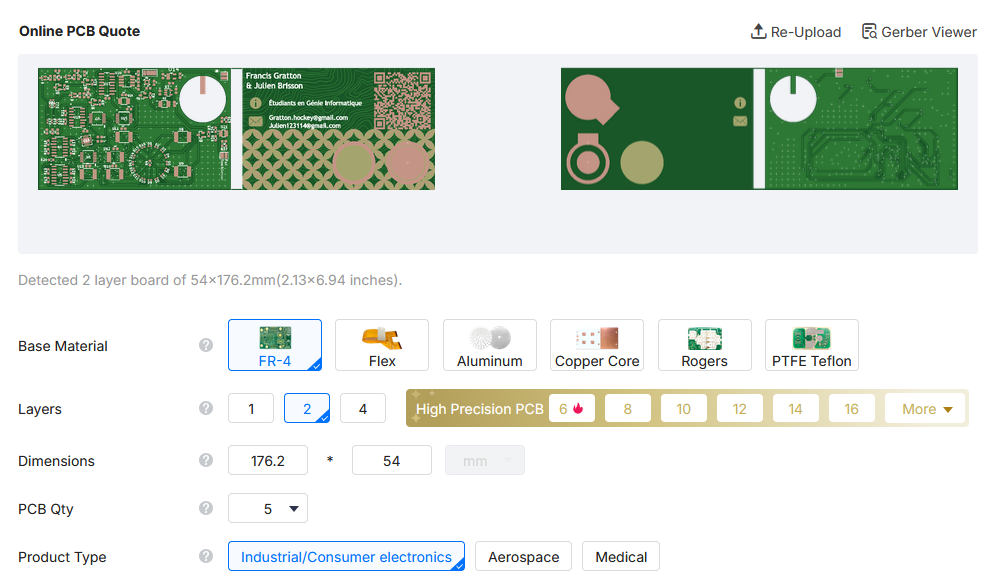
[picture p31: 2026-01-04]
Remise/setup.png

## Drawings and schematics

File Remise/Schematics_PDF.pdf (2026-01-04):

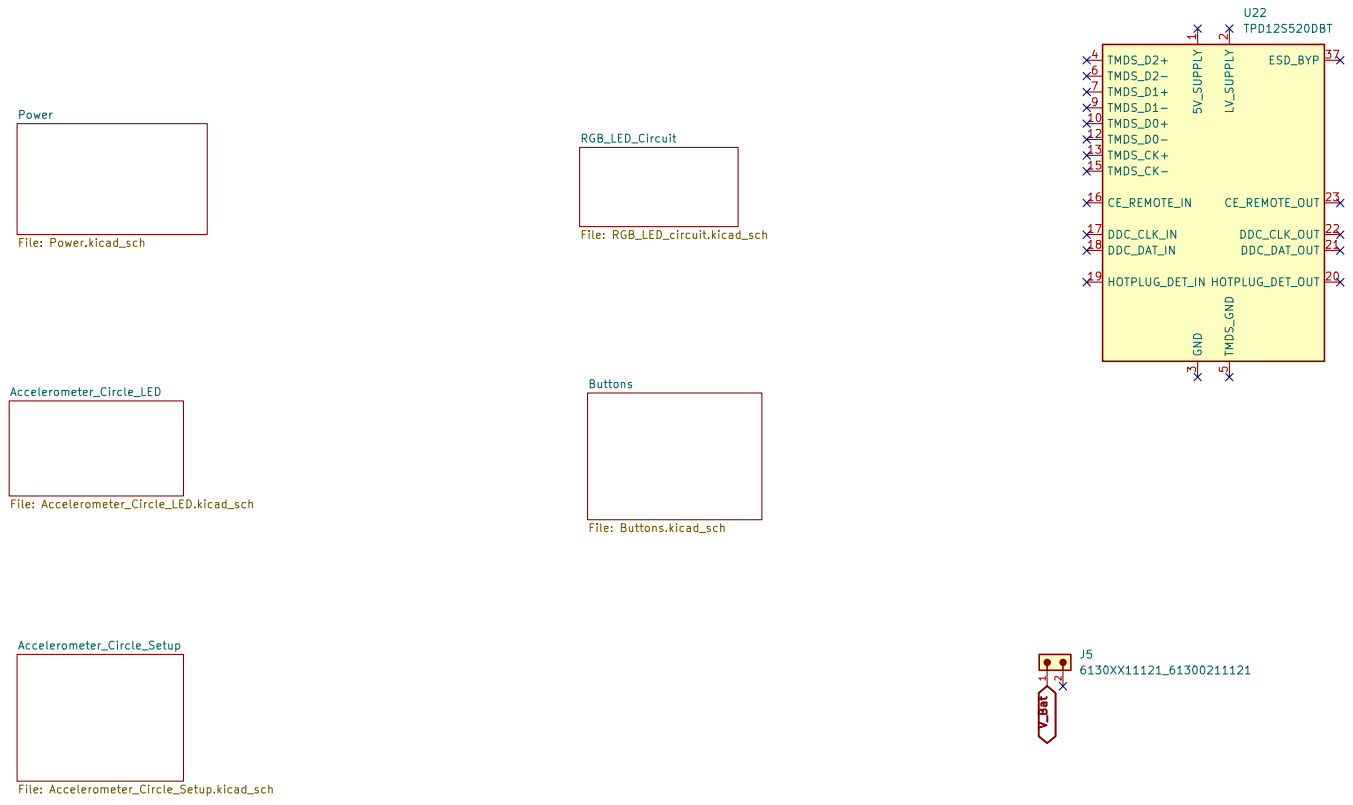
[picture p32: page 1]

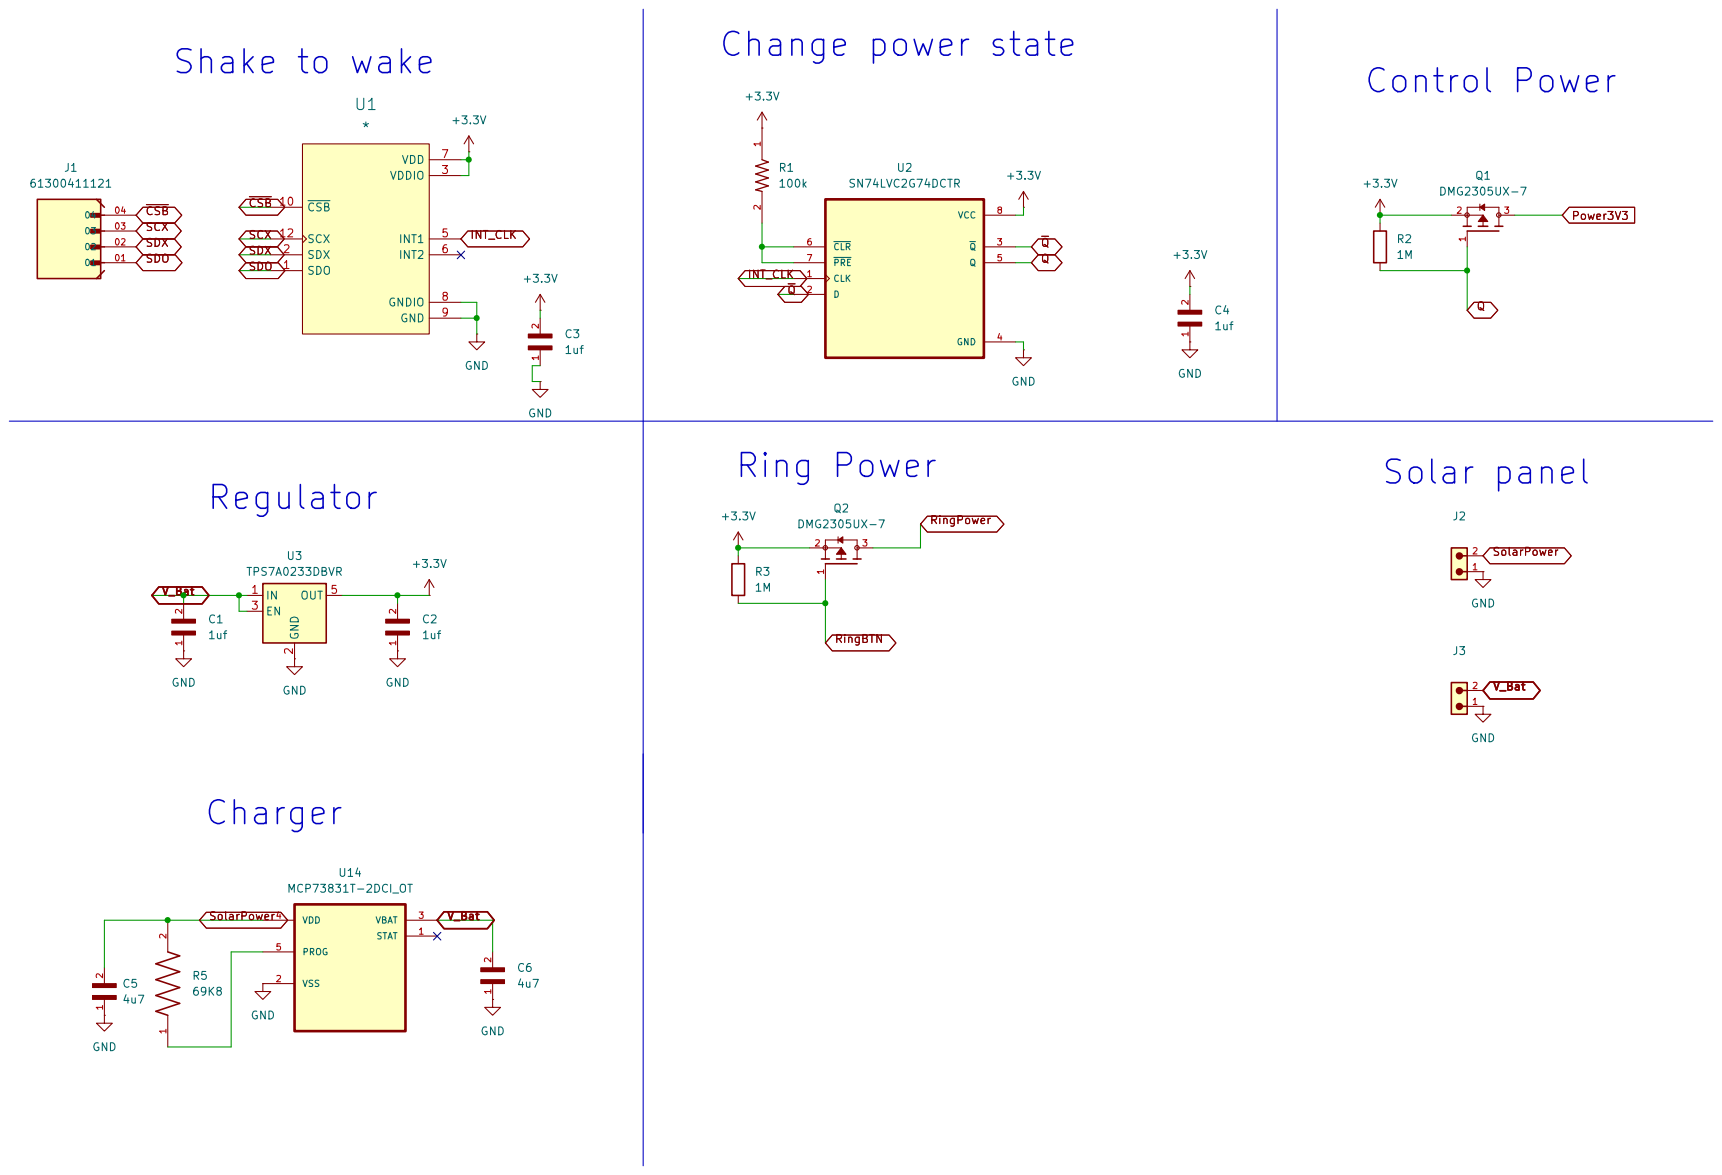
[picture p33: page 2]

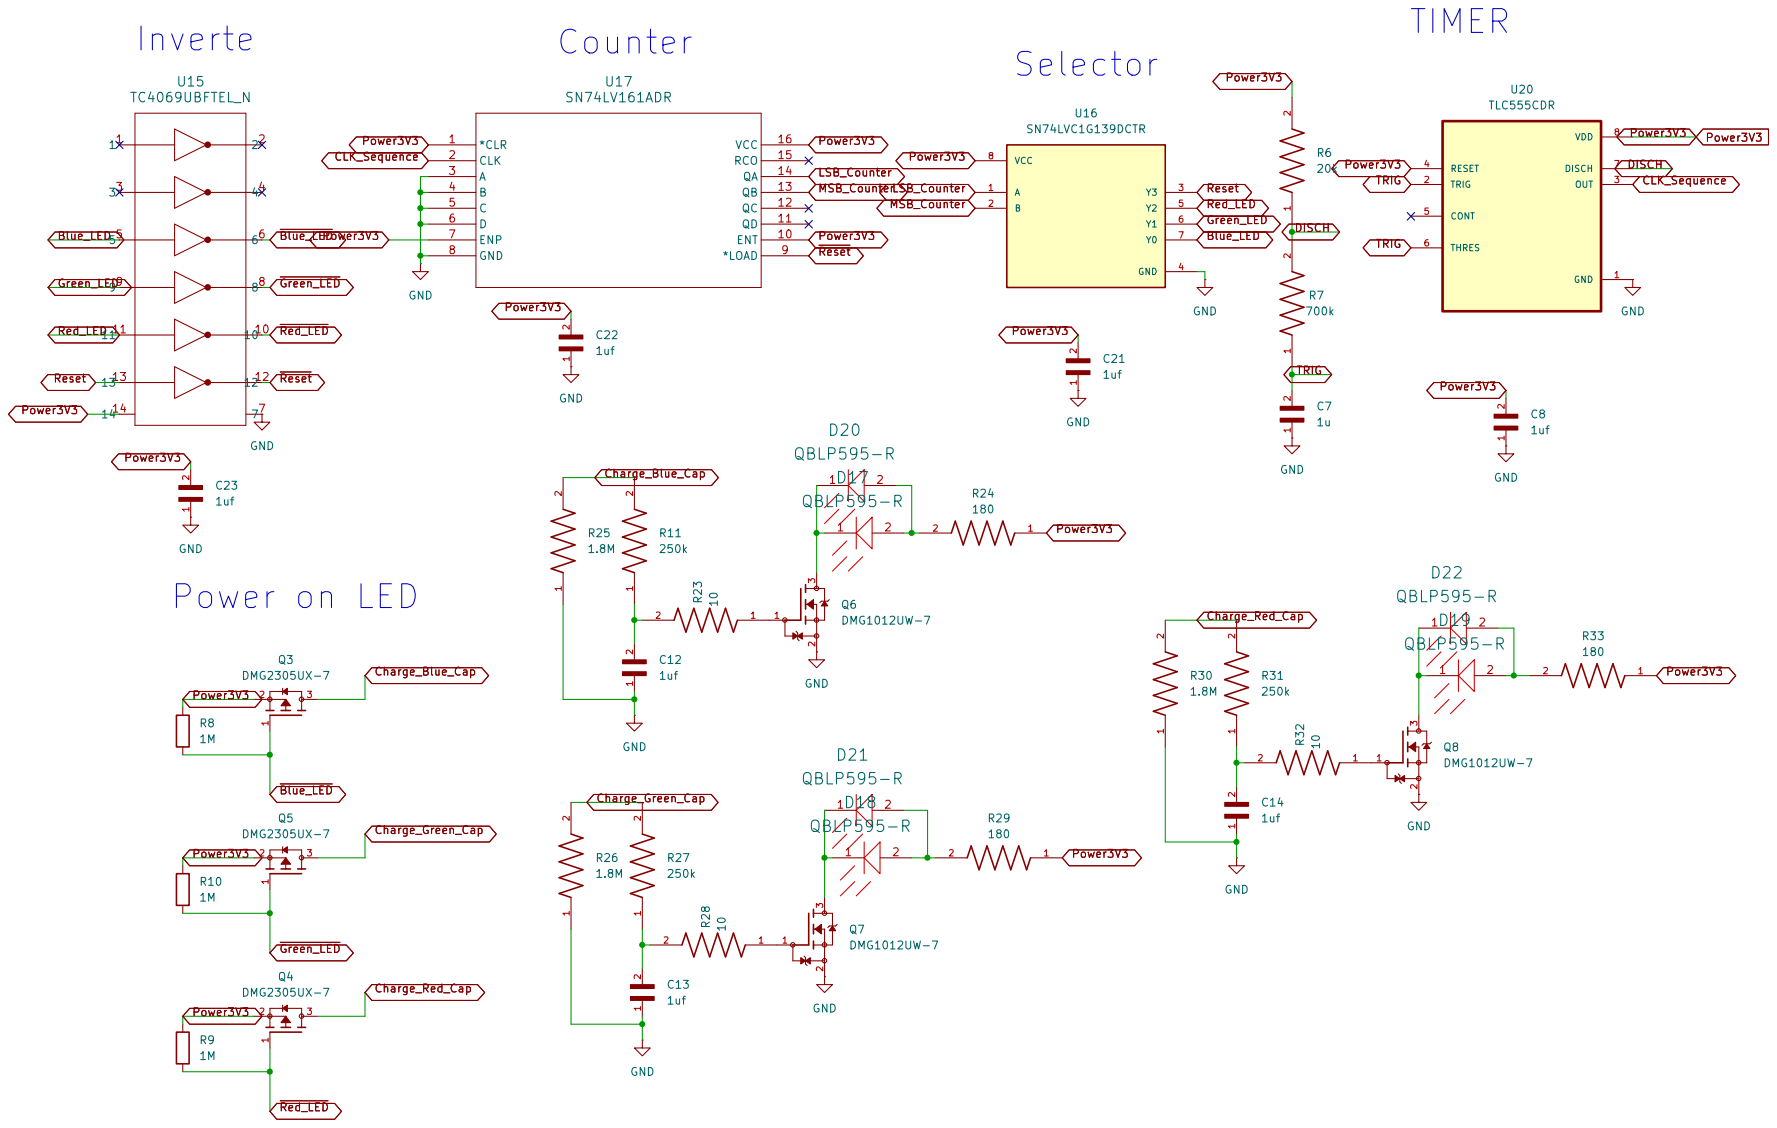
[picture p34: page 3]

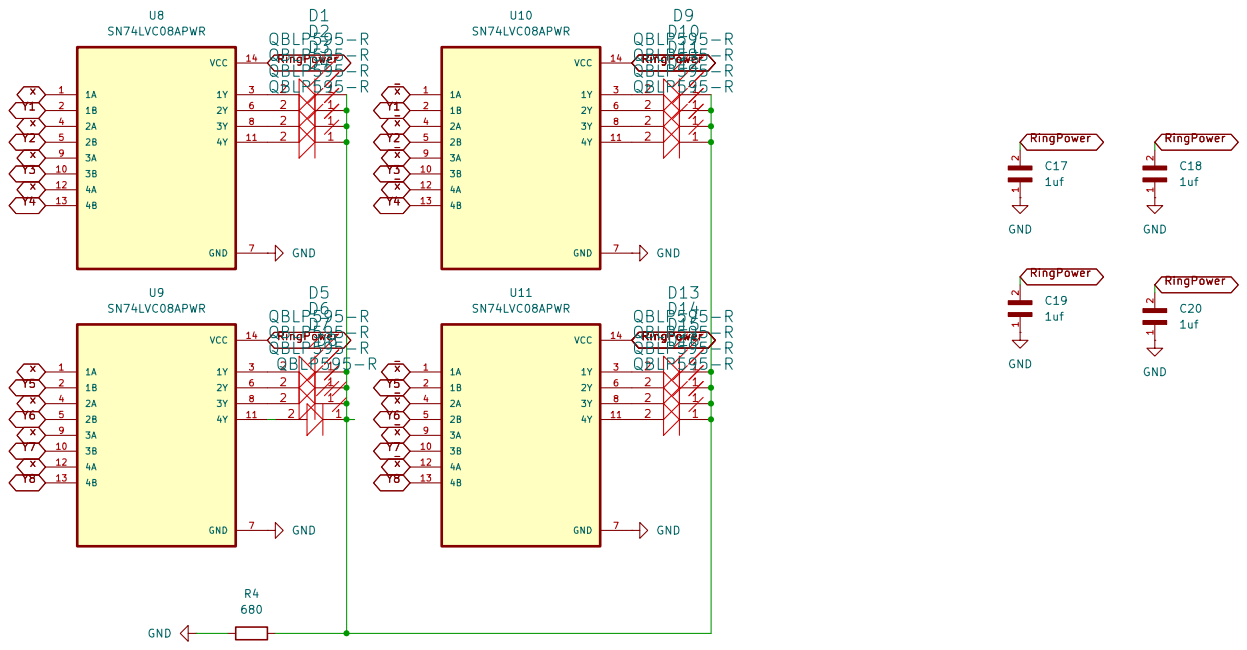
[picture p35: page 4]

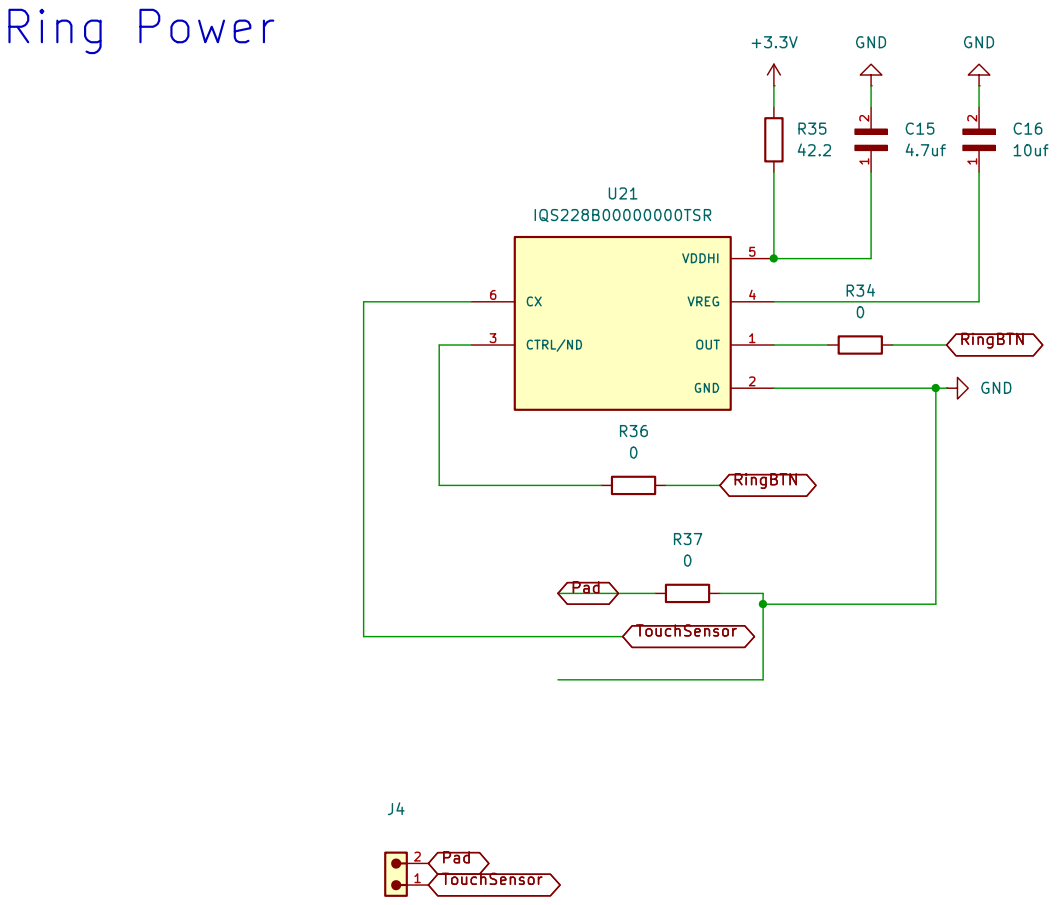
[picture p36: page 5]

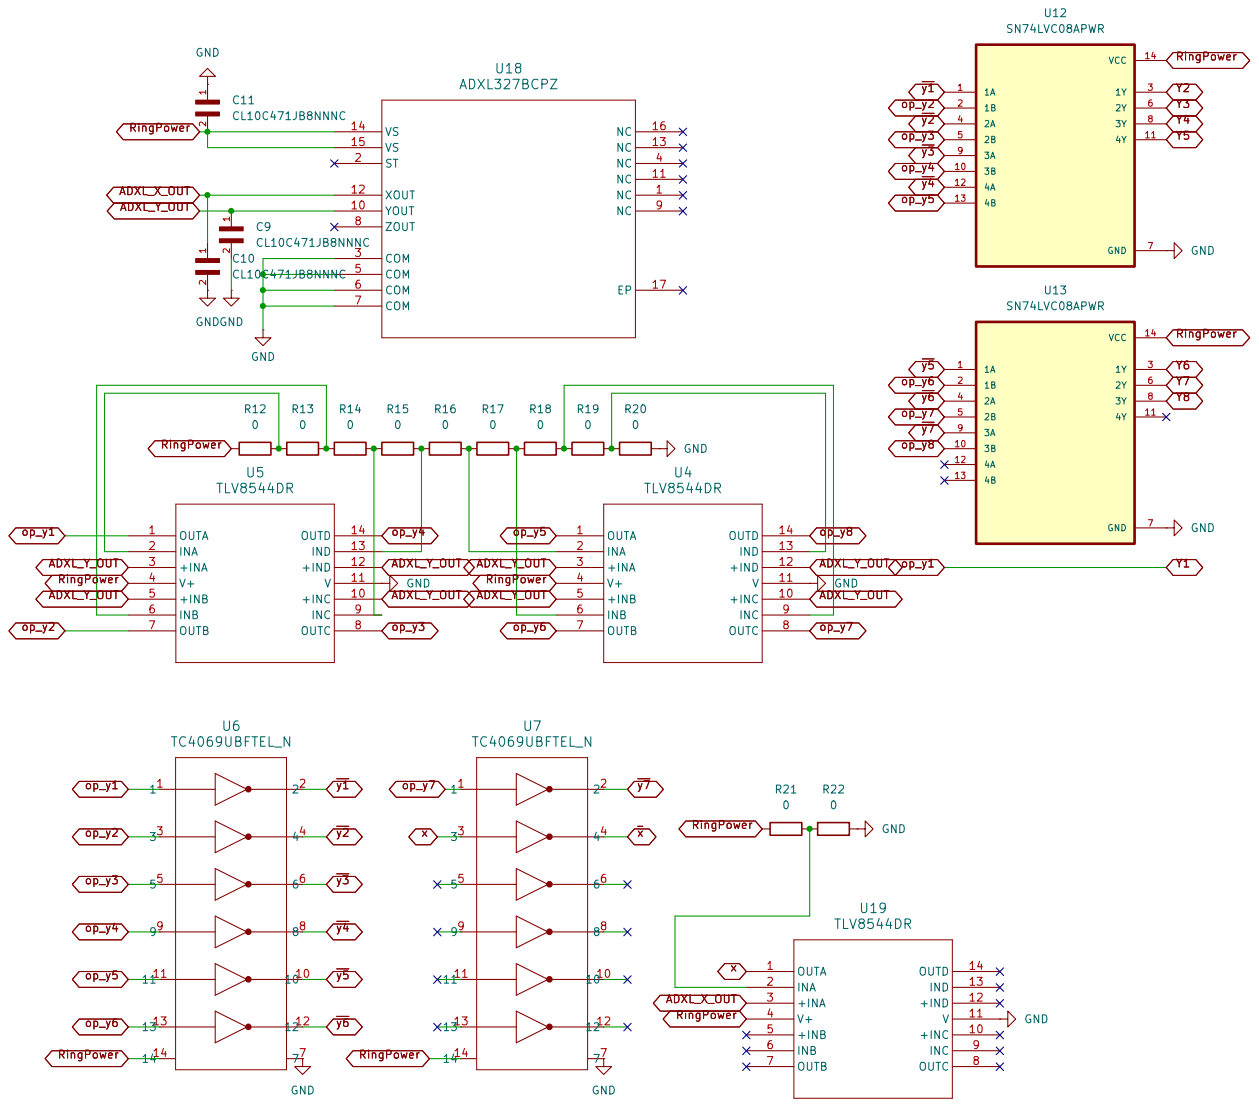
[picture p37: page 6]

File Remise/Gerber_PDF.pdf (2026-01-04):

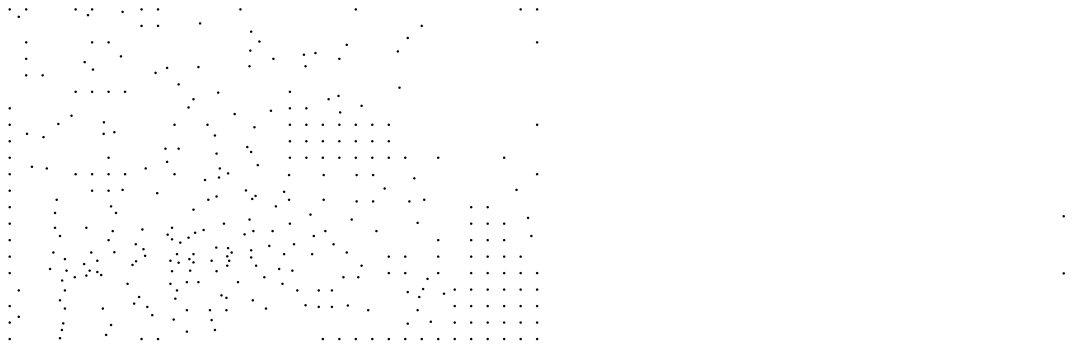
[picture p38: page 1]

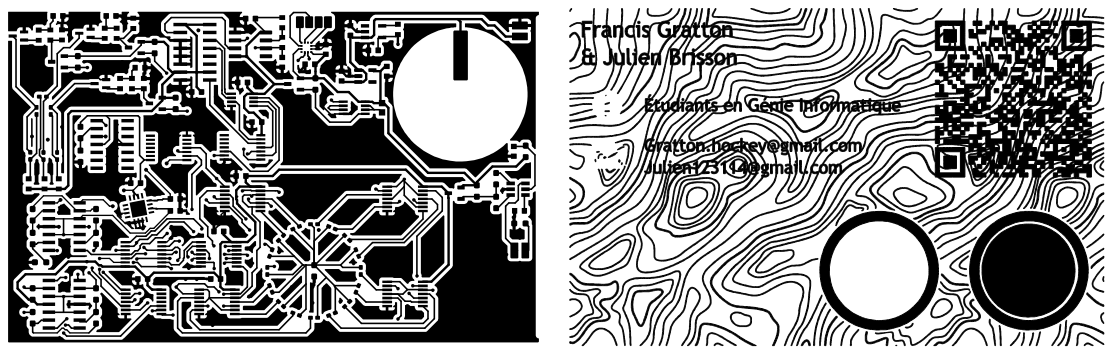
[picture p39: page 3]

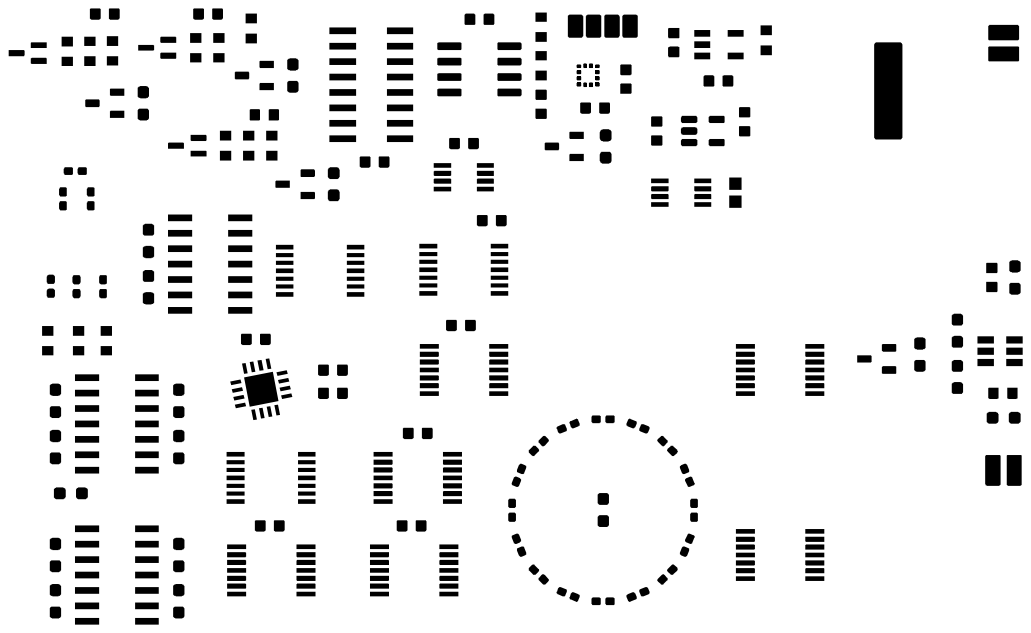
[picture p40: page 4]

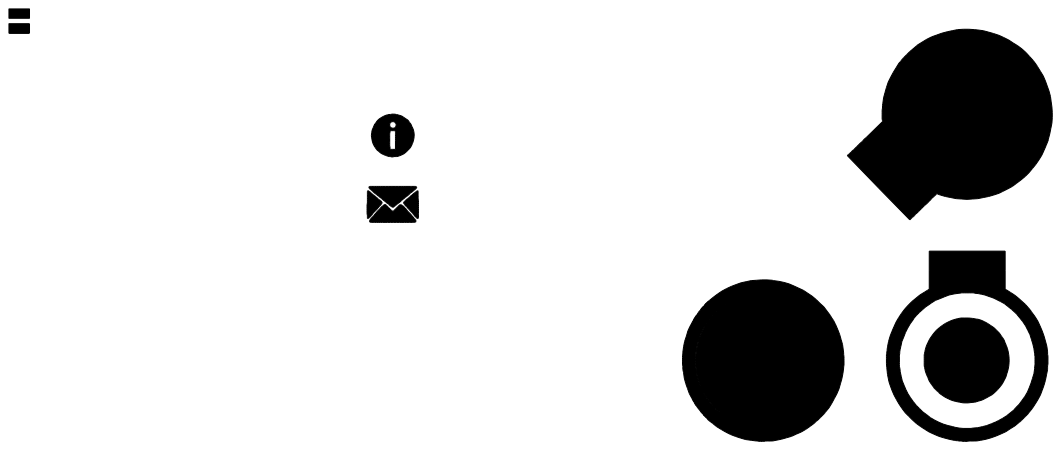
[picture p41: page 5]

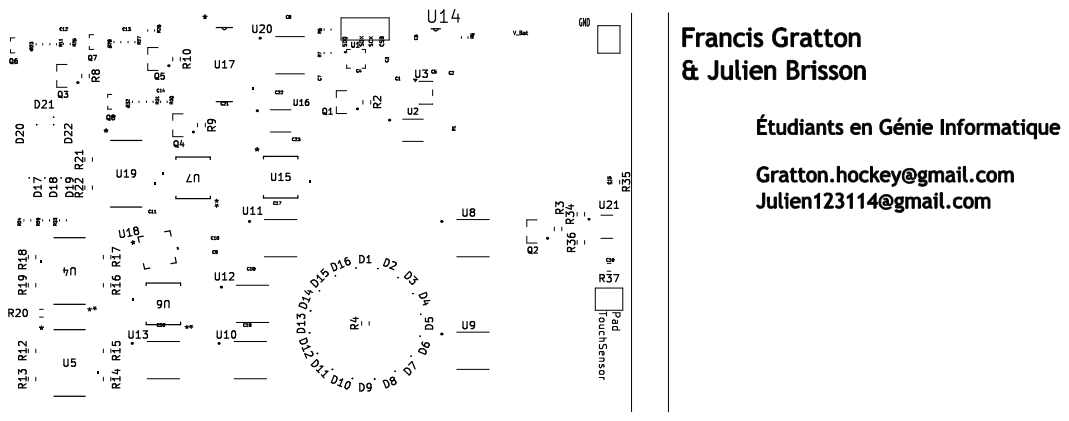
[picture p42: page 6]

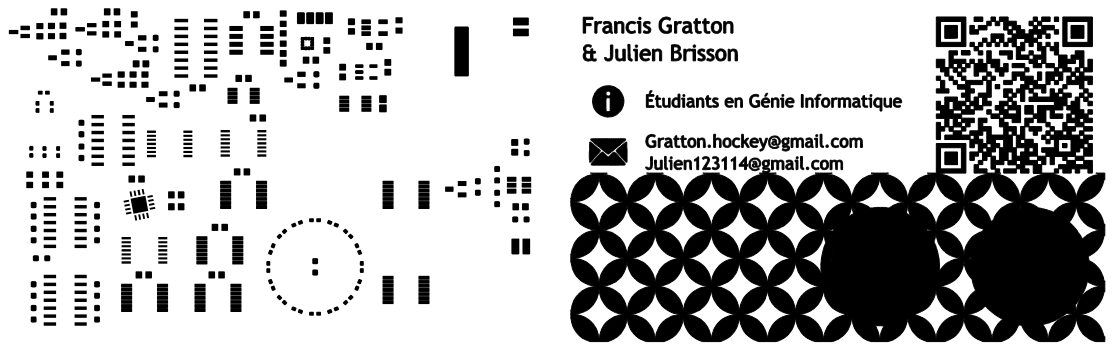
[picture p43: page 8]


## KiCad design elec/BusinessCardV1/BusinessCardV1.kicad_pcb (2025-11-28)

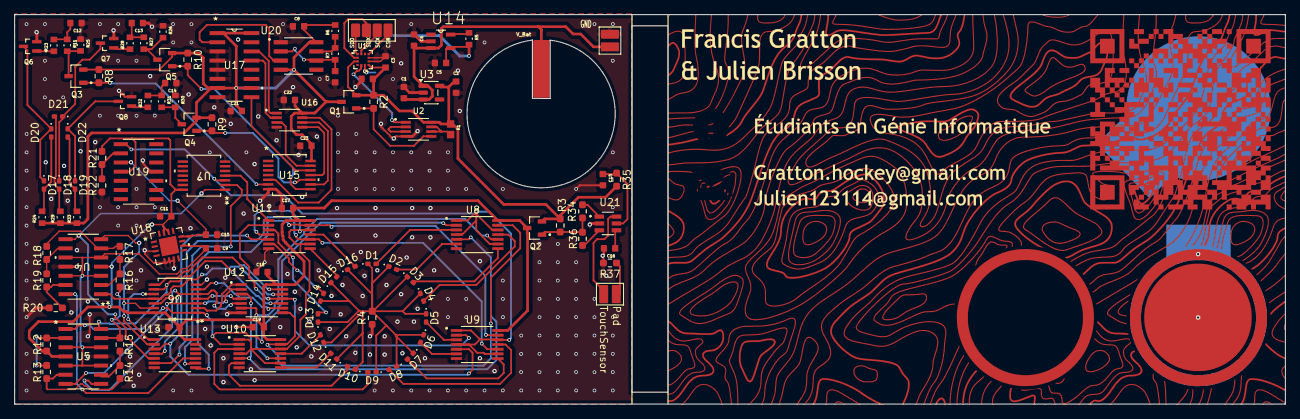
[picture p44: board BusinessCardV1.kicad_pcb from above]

Board: 2 copper layers, 176.2 x 54.0 mm, 117 parts (1 on the bottom side), 102 nets.

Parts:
C1, C2, C3, C4, C8, C12, C13, C14, C17, C18, C19, C20, C21, C22, C23: 1uf; CAPC1608X90N
C5, C6: 4u7; CAPC1608X90N
C7: 1u; CAPC1608X90N
C9, C10, C11: CL10C471JB8NNNC; CAPC1608X90N
C15: 4.7uf; CAPC1608X90N
C16: 10uf; CAPC1608X90N
D1, D2, D3, D4, D5, D6, D7, D8, D9, D10, D11, D12, D13, D14, D15, D16, D17, D18, D19, D20, D21, D22: QBLP595-R; LED_0402_1005Metric_Pad0.77x0.64mm_HandSolder
J1: 61300411121; HEADER1x4_SMD
J2, J3, J4: 6130XX11121_61300211121; Header1x2_SMD
J5: 6130XX11121_61300211121; SMD_Header
Q1, Q2, Q3, Q4, Q5: DMG2305UX-7; SOT91P240X110-3N_DMG2305UX-7
Q6, Q7, Q8: DMG1012UW-7; SOT65P222X110-3N
R1: 100k; RESC1607X60N
R2, R3, R8, R9, R10: 1M; R_0603_1608Metric_Pad0.98x0.95mm_HandSolder
R4: 680; R_0603_1608Metric_Pad0.98x0.95mm_HandSolder
R5: 69K8; RESC1608X55N
R6: 20k; RESC1608X55N
R7: 700k; RESC1608X55N
R11, R27, R31: 250k; RESC1608X55N
R12, R13, R14, R15, R16, R17, R18, R19, R20, R21, R22, R34, R36, R37: 0; R_0603_1608Metric_Pad0.98x0.95mm_HandSolder
R23, R28, R32: 10; RESC1608X55N
R24, R29, R33: 180; RESC1608X55N
R25, R26, R30: 1.8M; RESC1608X55N
R35: 42.2; R_0603_1608Metric_Pad0.98x0.95mm_HandSolder
U1: *; XDCR_BMA400
U2: SN74LVC2G74DCTR; SOP65P400X130-8N
U3: TPS7A0233DBVR; SOT-23-5
U4, U5, U19: TLV8544DR; D14_TEX
U6, U7, U15: TC4069UBFTEL_N; TSSOP14_TOS
U8, U9, U10, U11, U12, U13: SN74LVC08APWR; SOP65P640X120-14N
U14: MCP73831T-2DCI_OT; SOT95P270X145-5N
U16: SN74LVC1G139DCTR; SOP65P400X130-8N
U17: SN74LV161ADR
U18: ADXL327BCPZ; CP_16_5A_ADI
U20: TLC555CDR; SOIC127P599X175-8N
U21: IQS228B00000000TSR; SOT95P280X100-6N
U22: TPD12S520DBT; design

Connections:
+3.3V: C2.2, C3.2, C4.2, Q1.2, Q2.2, R1.1, R2.1, R3.1, R35.2, U1.3 (VDDIO), U1.7 (VDD), U2.8 (VCC), U3.5 (OUT)
ADXL_X_OUT: C10.1, U18.12 (XOUT), U19.3 (+INA)
ADXL_Y_OUT: C9.1, U4.3 (+INA), U4.5 (+INB), U4.10 (+INC), U4.12 (+IND), U5.3 (+INA), U5.5 (+INB), U5.10 (+INC), U5.12 (+IND), U18.10 (YOUT)
Blue_LED: U15.5, U16.7 (Y0)
CLK_Sequence: U17.2 (CLK), U20.3 (OUT)
Charge_Blue_Cap: Q3.3, R11.2, R25.2
Charge_Green_Cap: Q5.3, R26.2, R27.2
Charge_Red_Cap: Q4.3, R30.2, R31.2
DISCH: R6.1, R7.2, U20.7 (DISCH)
GND: C1.1, C2.1, C3.1, C4.1, C5.1, C6.1, C7.1, C8.1, C9.2, C10.2, C11.1, C12.1, C13.1, C14.1, C15.2, C16.2, C17.1, C18.1, C19.1, C20.1, C21.1, C22.1, C23.1, J2.1, J3.1, Q6.2, Q7.2, Q8.2, R4.1, R20.2, R22.2, R25.1, R26.1, R30.1, R37.1, U1.8 (GNDIO), U1.9 (GND), U2.4 (GND), U3.2 (GND), U4.11 (V), U5.11 (V), U6.7, U7.7, U8.7 (GND), U9.7 (GND), U10.7 (GND), U11.7 (GND), U12.7 (GND), U13.7 (GND), U14.2 (VSS), U15.7, U16.4 (GND), U17.3 (A), U17.4 (B), U17.5 (C), U17.6 (D), U17.8 (GND), U18.3 (COM), U18.5 (COM), U18.6 (COM), U18.7 (COM), U19.11 (V), U20.1 (GND), U21.2 (GND)
Green_LED: U15.9, U16.6 (Y1)
INT_CLK: U1.5 (INT1), U2.1 (CLK)
LSB_Counter: U16.1 (A), U17.14 (QA)
MSB_Counter: U16.2 (B), U17.13 (QB)
unnamed: C12.2, R11.1, R23.2
unnamed: C13.2, R27.1, R28.2
unnamed: C14.2, R31.1, R32.2
unnamed: D1.2 (ANODE_(+)), U8.3 (1Y)
unnamed: D1.1 (CATHODE_(-)), D2.1 (CATHODE_(-)), D3.1 (CATHODE_(-)), D4.1 (CATHODE_(-)), D5.1 (CATHODE_(-)), D6.1 (CATHODE_(-)), D7.1 (CATHODE_(-)), D8.1 (CATHODE_(-)), D9.1 (CATHODE_(-)), D10.1 (CATHODE_(-)), D11.1 (CATHODE_(-)), D12.1 (CATHODE_(-)), D13.1 (CATHODE_(-)), D14.1 (CATHODE_(-)), D15.1 (CATHODE_(-)), D16.1 (CATHODE_(-)), R4.2
unnamed: D2.2 (ANODE_(+)), U8.6 (2Y)
unnamed: D3.2 (ANODE_(+)), U8.8 (3Y)
unnamed: D4.2 (ANODE_(+)), U8.11 (4Y)
unnamed: D5.2 (ANODE_(+)), U9.3 (1Y)
unnamed: D6.2 (ANODE_(+)), U9.6 (2Y)
unnamed: D7.2 (ANODE_(+)), U9.8 (3Y)
unnamed: D8.2 (ANODE_(+)), U9.11 (4Y)
unnamed: D9.2 (ANODE_(+)), U10.3 (1Y)
unnamed: D10.2 (ANODE_(+)), U10.6 (2Y)
unnamed: D11.2 (ANODE_(+)), U10.8 (3Y)
unnamed: D12.2 (ANODE_(+)), U10.11 (4Y)
unnamed: D13.2 (ANODE_(+)), U11.3 (1Y)
unnamed: D14.2 (ANODE_(+)), U11.6 (2Y)
unnamed: D15.2 (ANODE_(+)), U11.8 (3Y)
unnamed: D16.2 (ANODE_(+)), U11.11 (4Y)
unnamed: D17.2 (ANODE_(+)), D20.2 (ANODE_(+)), R24.2
unnamed: D17.1 (CATHODE_(-)), D20.1 (CATHODE_(-)), Q6.3
unnamed: D18.2 (ANODE_(+)), D21.2 (ANODE_(+)), R29.2
unnamed: D18.1 (CATHODE_(-)), D21.1 (CATHODE_(-)), Q7.3
unnamed: D19.2 (ANODE_(+)), D22.2 (ANODE_(+)), R33.2
unnamed: D19.1 (CATHODE_(-)), D22.1 (CATHODE_(-)), Q8.3
unnamed: Q6.1, R23.1
unnamed: Q7.1, R28.1
unnamed: Q8.1, R32.1
unnamed: R1.2, U2.6 (~CLR), U2.7 (~PRE)
unnamed: R16.2, R17.1, U4.2 (INA)
unnamed: R17.2, R18.1, U4.6 (INB)
unnamed: R18.2, R19.1, U4.9 (INC)
unnamed: R19.2, R20.1, U4.13 (IND)
unnamed: R12.2, R13.1, U5.2 (INA)
unnamed: R13.2, R14.1, U5.6 (INB)
unnamed: R14.2, R15.1, U5.9 (INC)
unnamed: R15.2, R16.1, U5.13 (IND)
unnamed: R5.1, U14.5 (PROG)
unnamed: R21.2, R22.1, U19.2 (INA)
unnamed: R36.2, U21.3 (CTRL/ND)
unnamed: R34.2, U21.1 (OUT)
unnamed: C15.1, R35.1, U21.5 (VDDHI)
unnamed: C16.1, U21.4 (VREG)
Pad: J4.2, R37.2
Power3V3: C8.2, C21.2, C22.2, C23.2, Q1.3, Q3.2, Q4.2, Q5.2, R6.2, R8.1, R9.1, R10.1, R24.1, R29.1, R33.1, U15.14, U16.8 (VCC), U17.1 (*CLR), U17.7 (ENP), U17.10 (ENT), U17.16 (VCC), U20.4 (RESET), U20.8 (VDD)
Q: Q1.1, R2.2, U2.5 (Q)
Red_LED: U15.11, U16.5 (Y2)
Reset: U15.13, U16.3 (Y3)
RingBTN: Q2.1, R3.2, R34.1, R36.1
RingPower: C11.2, C17.2, C18.2, C19.2, C20.2, Q2.3, R12.1, R21.1, U4.4 (V+), U5.4 (V+), U6.14, U7.14, U8.14 (VCC), U9.14 (VCC), U10.14 (VCC), U11.14 (VCC), U12.14 (VCC), U13.14 (VCC), U18.14 (VS), U18.15 (VS), U19.4 (V+)
SCX: J1.03, U1.12 (SCX)
SDO: J1.01, U1.1 (SDO)
SDX: J1.02, U1.2 (SDX)
SolarPower: C5.2, J2.2, R5.2, U14.4 (VDD)
TRIG: C7.2, R7.1, U20.2 (TRIG), U20.6 (THRES)
TouchSensor: J4.1, U21.6 (CX)
V_Bat: C1.2, C6.2, J3.2, J5.1, U3.1 (IN), U3.3 (EN), U14.3 (VBAT)
Y1: U5.1 (OUTA), U6.1, U8.2 (1B), U10.2 (1B)
Y2: U8.5 (2B), U10.5 (2B), U12.3 (1Y)
Y3: U8.10 (3B), U10.10 (3B), U12.6 (2Y)
Y4: U8.13 (4B), U10.13 (4B), U12.8 (3Y)
Y5: U9.2 (1B), U11.2 (1B), U12.11 (4Y)
Y6: U9.5 (2B), U11.5 (2B), U13.3 (1Y)
Y7: U9.10 (3B), U11.10 (3B), U13.6 (2Y)
Y8: U9.13 (4B), U11.13 (4B), U13.8 (3Y)
op_y2: U5.7 (OUTB), U6.3, U12.2 (1B)
op_y3: U5.8 (OUTC), U6.5, U12.5 (2B)
op_y4: U5.14 (OUTD), U6.9, U12.10 (3B)
op_y5: U4.1 (OUTA), U6.11, U12.13 (4B)
op_y6: U4.7 (OUTB), U6.13, U13.2 (1B)
op_y7: U4.8 (OUTC), U7.1, U13.5 (2B)
op_y8: U4.14 (OUTD), U13.10 (3B)
x: U7.3, U8.1 (1A), U8.4 (2A), U8.9 (3A), U8.12 (4A), U9.1 (1A), U9.4 (2A), U9.9 (3A), U9.12 (4A), U19.1 (OUTA)
~Blue_LED: Q3.1, R8.2, U15.6
~CSB: J1.04, U1.10 (~CSB)
~Green_LED: Q5.1, R10.2, U15.8
~Q: U2.2 (D), U2.3 (~Q)
~Red_LED: Q4.1, R9.2, U15.10
~Reset: U15.12, U17.9 (*LOAD)
~x: U7.4, U10.1 (1A), U10.4 (2A), U10.9 (3A), U10.12 (4A), U11.1 (1A), U11.4 (2A), U11.9 (3A), U11.12 (4A)
~y1: U6.2, U12.1 (1A)
~y2: U6.4, U12.4 (2A)
~y3: U6.6, U12.9 (3A)
~y4: U6.8, U12.12 (4A)
~y5: U6.10, U13.1 (1A)
~y6: U6.12, U13.4 (2A)
~y7: U7.2, U13.9 (3A)

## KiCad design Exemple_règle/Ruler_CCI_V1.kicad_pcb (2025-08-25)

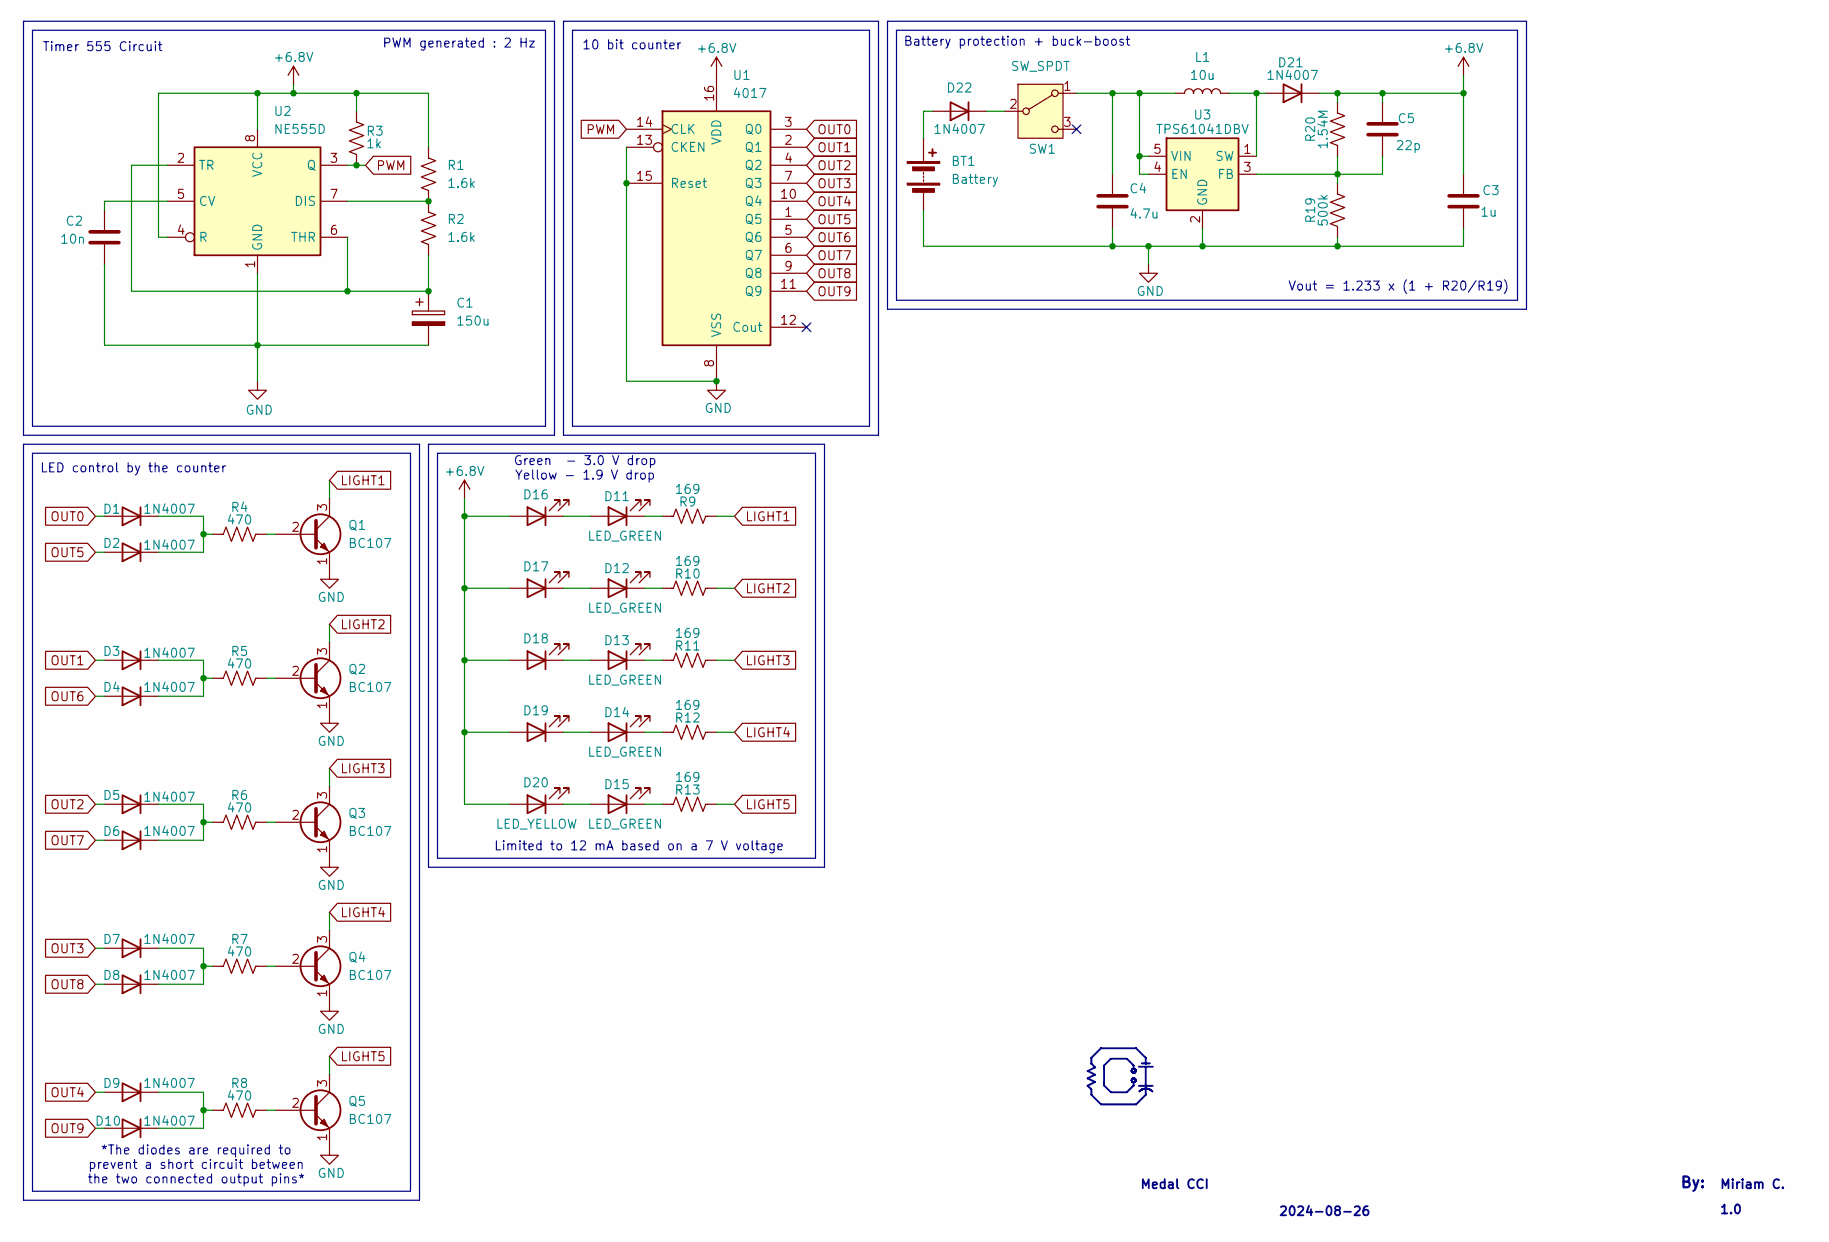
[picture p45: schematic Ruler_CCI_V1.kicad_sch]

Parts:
BT1: Battery; BAT_SMD_CR1220
C1: 150u; CP_Elec_6.3x7.7
C2: 10n; C_0603_1608Metric
C3: 1u; L_0603_1608Metric_Pad1.05x0.95mm_HandSolder
C4: 4.7u; L_0603_1608Metric_Pad1.05x0.95mm_HandSolder
C5: 22p; L_0603_1608Metric_Pad1.05x0.95mm_HandSolder
D1, D2, D3, D4, D5, D6, D7, D8, D9, D10, D21, D22: 1N4007; D_SOD-123F
D11, D12, D13, D14, D15: LED_GREEN; D_0603_1608Metric_Pad1.05x0.95mm_HandSolder
D16, D17, D18, D19, D20: LED_YELLOW; D_0603_1608Metric_Pad1.05x0.95mm_HandSolder
L1: 10u; L_0805_2012Metric_Pad1.15x1.40mm_HandSolder
Q1, Q2, Q3, Q4, Q5: BC107; SOT-23
R1, R2: 1.6k; R_0603_1608Metric_Pad0.98x0.95mm_HandSolder
R3: 1k; R_0603_1608Metric_Pad0.98x0.95mm_HandSolder
R4, R5, R6, R7, R8: 470; R_0603_1608Metric_Pad0.98x0.95mm_HandSolder
R9, R10, R11, R12, R13: 169; R_0603_1608Metric_Pad0.98x0.95mm_HandSolder
R19: 500k; R_0603_1608Metric_Pad0.98x0.95mm_HandSolder
R20: 1.54M; R_0603_1608Metric_Pad0.98x0.95mm_HandSolder
SW1: SW_SPDT; SW_SPDT_PCM12
U1: 4017; SOP-16_3.9x9.9mm_P1.27mm
U2: NE555D; SOIC-8_3.9x4.9mm_P1.27mm
U3: TPS61041DBV; SOT-23-5

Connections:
+6.8V: C3.1, C5.1, D16.2 (A), D17.2 (A), D18.2 (A), D19.2 (A), D20.2 (A), D21.1 (K), R1.1, R3.1, R20.2, U1.16 (VDD), U2.4 (R), U2.8 (VCC)
GND: BT1.2 (-), C1.2, C2.2, C3.2, C4.2, Q1.1 (E), Q2.1 (E), Q3.1 (E), Q4.1 (E), Q5.1 (E), R19.1, U1.8 (VSS), U1.13 (CKEN), U1.15 (Reset), U2.1 (GND), U3.2 (GND)
LIGHT1: Q1.3 (C), R9.1
LIGHT2: Q2.3 (C), R10.1
LIGHT3: Q3.3 (C), R11.1
LIGHT4: Q4.3 (C), R12.1
LIGHT5: Q5.3 (C), R13.1
unnamed: BT1.1 (+), D22.2 (A)
unnamed: D1.1 (K), D2.1 (K), R4.1
unnamed: D3.1 (K), D4.1 (K), R5.1
unnamed: D5.1 (K), D6.1 (K), R6.1
unnamed: D7.1 (K), D8.1 (K), R7.1
unnamed: D9.1 (K), D10.1 (K), R8.1
unnamed: D11.2 (A), D16.1 (K)
unnamed: D11.1 (K), R9.2
unnamed: D12.2 (A), D17.1 (K)
unnamed: D12.1 (K), R10.2
unnamed: D13.2 (A), D18.1 (K)
unnamed: D13.1 (K), R11.2
unnamed: D14.2 (A), D19.1 (K)
unnamed: D14.1 (K), R12.2
unnamed: D15.2 (A), D20.1 (K)
unnamed: D15.1 (K), R13.2
unnamed: D21.2 (A), L1.2, U3.1 (SW)
unnamed: D22.1 (K), SW1.2 (B)
unnamed: Q1.2 (B), R4.2
unnamed: Q2.2 (B), R5.2
unnamed: Q3.2 (B), R6.2
unnamed: Q4.2 (B), R7.2
unnamed: Q5.2 (B), R8.2
unnamed: C4.1, L1.1, SW1.1 (A), U3.4 (EN), U3.5 (VIN)
unnamed: C2.1, U2.5 (CV)
unnamed: R1.2, R2.1, U2.7 (DIS)
unnamed: C1.1, R2.2, U2.2 (TR), U2.6 (THR)
unnamed: C5.2, R19.2, R20.1, U3.3 (FB)
OUT0: D1.2 (A), U1.3 (Q0)
OUT1: D3.2 (A), U1.2 (Q1)
OUT2: D5.2 (A), U1.4 (Q2)
OUT3: D7.2 (A), U1.7 (Q3)
OUT4: D9.2 (A), U1.10 (Q4)
OUT5: D2.2 (A), U1.1 (Q5)
OUT6: D4.2 (A), U1.5 (Q6)
OUT7: D6.2 (A), U1.6 (Q7)
OUT8: D8.2 (A), U1.9 (Q8)
OUT9: D10.2 (A), U1.11 (Q9)
PWM: R3.2, U1.14 (CLK), U2.3 (Q)

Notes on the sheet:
Miriam C.
10 bit counter
2024-08-26
Limited to 12 mA based on a 7 V voltage
LED control by the counter
Green - 3.0 V drop Yellow - 1.9 V drop
By:
1.0
Battery protection + buck-boost
PWM generated : 2 Hz
Timer 555 Circuit
*The diodes are required to prevent a short circuit between the two connected output pins*
Vout = 1.233 x (1 + R20/R19)
Medal CCI

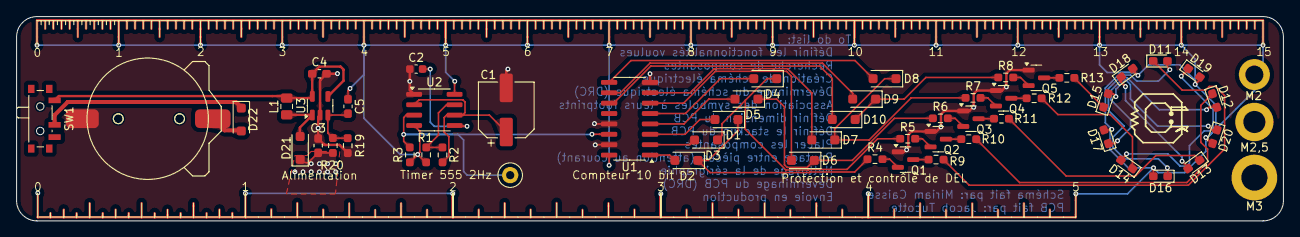
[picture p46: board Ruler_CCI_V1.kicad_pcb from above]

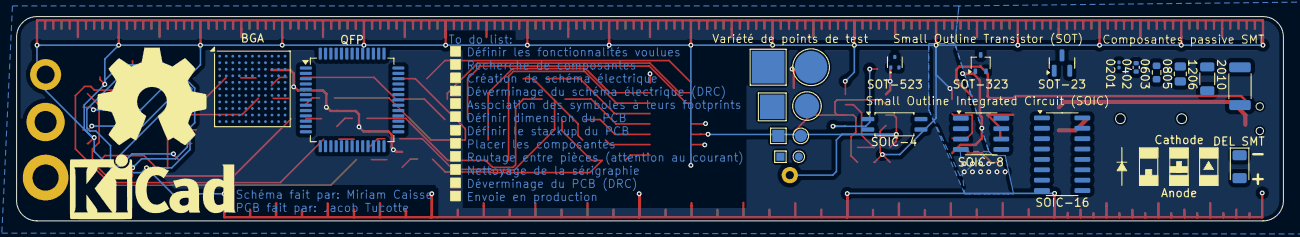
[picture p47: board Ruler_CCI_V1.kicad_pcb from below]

Board: 2 copper layers, 155.0 x 25.0 mm, 71 parts (15 on the bottom side), 46 nets.

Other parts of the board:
0201: R_0201_0603Metric
0402: R_0402_1005Metric
0603: R_0603_1608Metric
0805: R_0805_2012Metric
1206: R_1206_3216Metric
2010: R_2010_5025Metric
BGA: BGA-121_9.0x9.0mm_Layout11x11_P0.8mm_Ball0.4mm_Pa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; BGA-121_9.0x9.0mm_Layout11x11_P0.8mm_Ball0.4mm_Pad0.35mm_NS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
DEL SMT: LED_1206_3216Metric
M2: MountingHole_2.2mm_M2_DIN965_Pad
M2,5: MountingHole_2.7mm_M2.5_DIN965_Pad
M3: MountingHole_3.2mm_M3_DIN965_Pad
QFP: LQFP-52_10x10mm_P0.65mm
SOIC-4: SOIC-4_4.55x2.6mm_P1.27mm
SOIC-8: SOIC-8_3.9x4.9mm_P1.27mm
SOIC-16: SOIC-16_3.9x9.9mm_P1.27mm
SOT-23: SOT-23
SOT-323: SOT-323_SC-70
SOT-523: SOT-523

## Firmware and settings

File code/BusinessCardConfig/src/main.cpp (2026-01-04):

// #include <Wire.h>
// #include "SparkFun_BMA400_Arduino_Library.h"

// // Create a new sensor object
// BMA400 accelerometer;

// // I2C address selection
// // uint8_t i2cAddress = BMA400_I2C_ADDRESS_DEFAULT; // 0x14
// uint8_t i2cAddress = BMA400_I2C_ADDRESS_SECONDARY; // 0x15

// // Pin used for interrupt detection
// int interruptPin = 2;

// // Flag to know when interrupts occur
// volatile bool interruptOccurred = false;

// void setup()
// {
//     // Start serial
//     Serial.begin(115200);
//     delay(5000);
//     Serial.println("BMA400 Example 6 - Motion Detection");

//     // Initialize the I2C library
//     Wire.begin();
//     delay(5000);

//     // Check if sensor is connected and initialize
//     // Address is optional (defaults to 0x14)
//     while(accelerometer.beginI2C(i2cAddress) != BMA400_OK)
//     {
//         // Not connected, inform user
//         Serial.println("Error: BMA400 not connected, check wiring and I2C address!");

//         // Wait a bit to see if connection is established
//         delay(1000);
//     }

//     Serial.println("BMA400 connected!");

//     accelerometer.setMode(BMA400_MODE_LOW_POWER);

//     // Here we configure the generic interrupt feature of the BMA400. It
//     // triggers an interrupt when the measured acceleration exceeds some
//     // reference acceleration that we can specify. There are several other
//     // parameters that can be configured, such as acceleration threshold,
//     // hysteresis, automatic reference updates, etc. The BMA400 has 2 generic
//     // interrupts that can be configured independently
//     bma400_gen_int_conf config =
//     {
//         .gen_int_thres = 50, // 8mg resolution (eg. gen_int_thres=5 results in 40mg)
//         .gen_int_dur = 50, // 10ms resolution (eg. gen_int_dur=5 results in 50ms)
//         .axes_sel = BMA400_AXIS_XYZ_EN, // Which axes to evaluate for interrupts (X/Y/Z in any combination)
//         .data_src = BMA400_DATA_SRC_ACCEL_FILT_2, // Which filter to use (must be 100Hz, datasheet recommends filter 2)
//         .criterion_sel = BMA400_ACTIVITY_INT, // Trigger interrupts when active or inactive
//         .evaluate_axes = BMA400_ANY_AXES_INT, // Logical combining of axes for interrupt condition (OR/AND)
//         .ref_update = BMA400_UPDATE_EVERY_TIME, // Whether to automatically update reference values
//         .hysteresis = BMA400_HYST_96_MG, // Hysteresis acceleration for noise rejection
//         .int_thres_ref_x = 0, // Raw 12-bit acceleration value
//         .int_thres_ref_y = 0, // Raw 12-bit acceleration value
//         .int_thres_ref_z = 128, // Raw 12-bit acceleration value (at 4g range (default), 512 = 1g)
//         .int_chan = BMA400_INT_CHANNEL_1 // Which pin to use for interrupts
//     };
//     accelerometer.setGeneric1Interrupt(&config);

//     bma400_wakeup_conf wakeconf = {
//       .wakeup_ref_update = BMA400_UPDATE_EVERY_TIME, // Whether to automatically update reference values
//       .sample_count = BMA400_SAMPLE_COUNT_3,
//       .wakeup_axes_en = BMA400_AXIS_XY_EN,
//       .int_wkup_threshold = 64,
//       .int_wkup_ref_x = 64, // Raw 12-bit acceleration value
//       .int_wkup_ref_y = 64, // Raw 12-bit acceleration value
//       .int_chan = BMA400_INT_CHANNEL_1 // Which pin to use for interrupts
//     };
//     if(0 == accelerometer.setWakeupInterrupt(&wakeconf))
//     {
//         Serial.println("Wakeup interrupt configured.");
//     }
//     else
//     {
//         Serial.println("Error configuring wakeup interrupt.");
//     }

//     bma400_auto_lp_conf lpconf = {
//       .auto_low_power_trigger = BMA400_AUTO_LP_TIMEOUT_EN, // drdy, gen1, timeout, timeout reset
//       .auto_lp_timeout_threshold = 400 // 2.5ms resolution (eg. 400 results in 1s)
//     };
//     accelerometer.setAutoLowPower(&lpconf);

//     // Here we configure the INT1 pin to push/pull mode, active high
//     accelerometer.setInterruptPinMode(BMA400_INT_CHANNEL_1, BMA400_INT_PUSH_PULL_ACTIVE_1);
    
//     // Enable auto wakeup interrupt condition
//     accelerometer.enableInterrupt(BMA400_AUTO_WAKEUP_EN, true);
//     // Enable generic 1 interrupt condition
//     // accelerometer.enableInterrupt(BMA400_GEN1_INT_EN, true);
    
//     // Setup interrupt handler debug only
//     //attachInterrupt(digitalPinToInterrupt(interruptPin), bma400InterruptHandler, RISING);
// }

// void loop()
// {
//     // Wait for interrupt to occur
//     if(interruptOccurred)
//     {
//         // Reset flag for next interrupt
//         interruptOccurred = false;

//         Serial.print("Interrupt occurred!");
//         Serial.print("\t");

//         // Get the interrupt status to know which condition triggered
//         uint16_t interruptStatus = 0;
//         accelerometer.getInterruptStatus(&interruptStatus);
        
//         // Check if this is the generic 1 interrupt condition
//         if(interruptStatus & BMA400_ASSERTED_GEN1_INT)
//         {
//             Serial.println("Motion detected!");
//         }
//         else
//         {
//             Serial.println("Wrong interrupt condition!");
//         }
//     }
// }

// void bma400InterruptHandler()
// {
//     interruptOccurred = true;
// }







#include <Wire.h>
#include "SparkFun_BMA400_Arduino_Library.h"

// Create a new sensor object
BMA400 accelerometer;

// I2C address selection
// uint8_t i2cAddress = BMA400_I2C_ADDRESS_DEFAULT; // 0x14
uint8_t i2cAddress = BMA400_I2C_ADDRESS_SECONDARY; // 0x15

// Pin used for interrupt detection
int interruptPin = 2;

// Flag to know when interrupts occur
volatile bool interruptOccurred = false;

void setup()
{
    // Start serial
    Serial.begin(115200);
    Serial.println("BMA400 Example 6 - Motion Detection");

    // Initialize the I2C library
    Wire.begin();

    delay(5000);
    // Check if sensor is connected and initialize
    // Address is optional (defaults to 0x14)
    while(accelerometer.beginI2C(i2cAddress) != BMA400_OK)
    {
        // Not connected, inform user
        Serial.println("Error: BMA400 not connected, check wiring and I2C address!");

        // Wait a bit to see if connection is established
        delay(1000);
    }

    Serial.println("BMA400 connected!");

    // Here we configure the generic interrupt feature of the BMA400. It
    // triggers an interrupt when the measured acceleration exceeds some
    // reference acceleration that we can specify. There are several other
    // parameters that can be configured, such as acceleration threshold,
    // hysteresis, automatic reference updates, etc. The BMA400 has 2 generic
    // interrupts that can be configured independently
    bma400_gen_int_conf config =
    {
        .gen_int_thres = 10, // 8mg resolution (eg. gen_int_thres=5 results in 40mg)
        .gen_int_dur = 50, // 10ms resolution (eg. gen_int_dur=5 results in 50ms)
        .axes_sel = BMA400_AXIS_XYZ_EN, // Which axes to evaluate for interrupts (X/Y/Z in any combination)
        .data_src = BMA400_DATA_SRC_ACCEL_FILT_2, // Which filter to use (must be 100Hz, datasheet recommends filter 2)
        .criterion_sel = BMA400_ACTIVITY_INT, // Trigger interrupts when active or inactive
        .evaluate_axes = BMA400_ANY_AXES_INT, // Logical combining of axes for interrupt condition (OR/AND)
        .ref_update = BMA400_UPDATE_EVERY_TIME, // Whether to automatically update reference values
        .hysteresis = BMA400_HYST_96_MG, // Hysteresis acceleration for noise rejection
        .int_thres_ref_x = 512, // Raw 12-bit acceleration value
        .int_thres_ref_y = 512, // Raw 12-bit acceleration value
        .int_thres_ref_z = 512, // Raw 12-bit acceleration value (at 4g range (default), 512 = 1g)
        .int_chan = BMA400_INT_CHANNEL_1 // Which pin to use for interrupts
    };
    if( 0 == accelerometer.setGeneric1Interrupt(&config))
    {
        Serial.println("Generic 1 interrupt configured.");
    }
    else
    {
        Serial.println("Error configuring generic 1 interrupt.");
    }
    
    // Here we configure the INT1 pin to push/pull mode, active high
    if(0 == accelerometer.setInterruptPinMode(BMA400_INT_CHANNEL_1, BMA400_INT_PUSH_PULL_ACTIVE_1))
    {
        Serial.println("Interrupt pin configured.");
    }
    else
    {
        Serial.println("Error configuring interrupt pin.");
    }
    
    // Enable generic 1 interrupt condition
    if(0 == accelerometer.enableInterrupt(BMA400_GEN1_INT_EN, true))
    {
        Serial.println("Generic 1 interrupt enabled.");
    }
    else
    {
        Serial.println("Error enabling generic 1 interrupt.");
    }
    
    // Setup interrupt handler
    // attachInterrupt(digitalPinToInterrupt(interruptPin), bma400InterruptHandler, RISING);
}

void loop()
{
    delay(1000);
    Serial.println("Checking for interrupt...");
}

void bma400InterruptHandler()
{
    interruptOccurred = true;
}

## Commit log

2025-08-25 redo push
    [Grille_correction_E25.xlsm, Ruler_CCI_V1.kicad_pcb, Ruler_CCI_V1.kicad_sch]
2025-09-03 Fix and pdf push
    [Grille_correction_E25.xlsm]
2025-10-15 Ajout atelier
    [C3I_Atelier_KiCad.kicad_pcb, C3I_Atelier_KiCad.kicad_sch]
2025-10-18 Kicad created
    [BusinessCardV1.kicad_pcb, BusinessCardV1.kicad_sch, Logic.kicad_sch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]
2025-10-18 Added BMA400
    [BMA400.step, Power.kicad_sch]
2025-10-18 Big Ballz
    [Power.kicad_sch]
2025-10-27 Started the power management
    [Accelerometer_Circle_LED.kicad_sch, BusinessCardV1.kicad_sch, CL10B105KP8NNNC.step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]
2025-10-27 forgot to close kicad before pushing
2025-10-27 Added header BMA400
    [Header1x4.step, Power.kicad_sch]
2025-10-28 Power finished
    [Buttons.kicad_sch, CL10A475KP8NNNC.step, CL10C471JB8NNNC.step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]
2025-10-29 Timer and starting LED circuit of RGB
    [RGB_LED_circuit.kicad_sch]
2025-10-29 Circle wiring
    [Accelerometer_Circle_LED.kicad_sch, Accelerometer_Circle_Setup.kicad_sch]
2025-10-31 Added a few things
    [BusinessCardV1.csv]
2025-11-23 Added timer 555
    [Accelerometer_Circle_LED.kicad_sch, Accelerometer_Circle_Setup.kicad_sch, BusinessCardV1.kicad_sch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]
2025-11-24 Je sais pas trop
    [RGB_LED_circuit.kicad_sch]
2025-11-25 Finished LED fade
    [DMG1012UW-7.step, RGB_LED_circuit.kicad_sch]
2025-11-26 Button working i guess i hope
    [Buttons.kicad_sch]
2025-11-27 All footprint and start of PCB
    [Accelerometer_Circle_LED.kicad_sch, Accelerometer_Circle_Setup.kicad_sch, BusinessCardV1.kicad_pcb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]
2025-11-27 pcb fix + round led layup
    [BusinessCardV1.kicad_pcb]
2025-11-27 Started layout
    [Accelerometer_Circle_Setup.kicad_sch, BusinessCardV1.kicad_pcb, Power.kicad_sch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]
2025-11-28 PCB art
    [BusinessCardV1.kicad_sch]
2025-11-28 Missing update
    [BusinessCardV1.kicad_sch]
2025-11-28 Pushé les poin zip
2025-11-28 Position made, but kicad lagging everytime i add a wire
    [BusinessCardV1.kicad_pcb, BusinessCardV1.kicad_sch]
2025-11-28 Push before destroying everything
    [BusinessCardV1.kicad_pcb, Power.kicad_sch, RGB_LED_circuit.kicad_sch]
2025-11-28 Easy part done, Glabel kind of worked
    [Accelerometer_Circle_LED.kicad_sch, Accelerometer_Circle_Setup.kicad_sch, BusinessCardV1.kicad_pcb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]
2025-11-28 PCB routed
    [Accelerometer_Circle_LED.kicad_sch, Accelerometer_Circle_Setup.kicad_sch, BusinessCardV1.kicad_pcb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]
2025-11-28 Gerber almost ready
    [BusinessCardV1-B_Cu.gbr, BusinessCardV1-B_Mask.gbr, BusinessCardV1-B_Paste.gbr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]
2025-11-28 Everything is good
    [BusinessCardV1-B_Cu.gbr, BusinessCardV1-B_Mask.gbr, BusinessCardV1-B_Paste.gbr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]
2026-01-04 Remise WIP
    [CommandBOM09.csv, Commande2_BestTeam_9.csv]
